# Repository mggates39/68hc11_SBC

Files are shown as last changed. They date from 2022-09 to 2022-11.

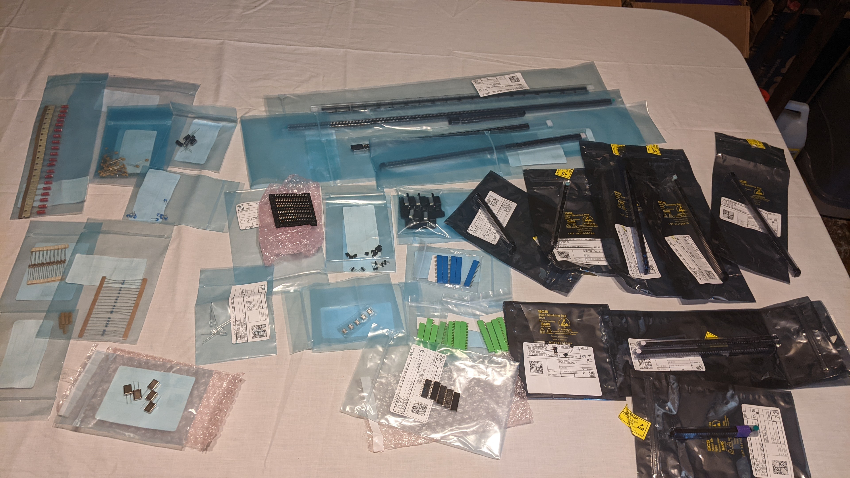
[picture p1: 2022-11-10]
BlogNotes/Digikey_Components/Components.jpg

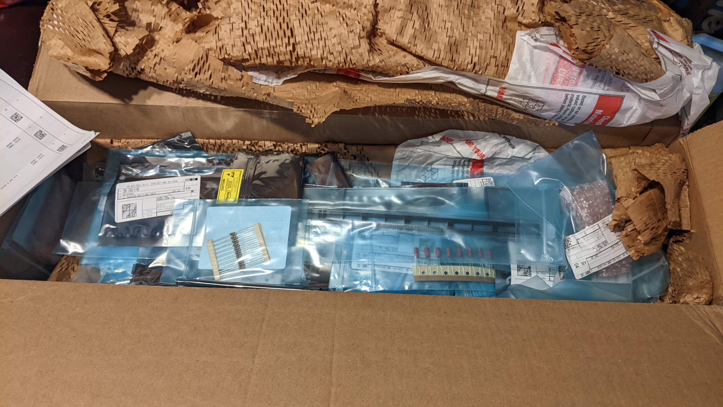
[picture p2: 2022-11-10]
BlogNotes/Digikey_Components/DigiKeyBox.jpg

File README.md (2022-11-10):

# 68hc11_SBC   [][License]
Building a Single Board Computer around the MC68HC11.  Specifically the XC68HC11A1FN - A38P8642.  It will include my first attempt with [KiCad](https://www.kicad.org/) designing a PCB

[][Manual]
[][Memory]

Software built with [TASM](https://www.ticalc.org/archives/files/fileinfo/250/25051.html)

Run in the [68HC11 Simulator](http://www.hc11.demon.nl/thrsim11/thrsim11.htm)

<!----------------------------------[ File links ]--------------------------------->

[License]: LICENSE
[Manual]: Documentation/Reference/68hc11%20Technical%20Manual.pdf
[Memory]: Documentation/Memory%20Map.md

<!----------------------------------[ Badges ]--------------------------------->

[Badge License]: https://img.shields.io/badge/License-GPL3-015d93.svg?style=for-the-badge&labelColor=blue

<!---------------------------------[ Buttons ]--------------------------------->

[Button Manual]: https://img.shields.io/badge/User_Manual-4285F4?style=for-the-badge&logoColor=white&logo=GitBook
[Button Memory]: https://img.shields.io/badge/Memory_Map-0F9D58?style=for-the-badge&logoColor=white&logo=Fitbit

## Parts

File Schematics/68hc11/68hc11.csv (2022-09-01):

Source: | /home/mggates/Dev/68hc11_SBC/Schematics/68hc11/68hc11.kicad_sch
Date: | Mon 29 Aug 2022 02:41:31 PM EDT
Tool: | Eeschema 6.0.2+dfsg-1
Generator: | /usr/share/kicad/plugins/bom_csv_grouped_by_value.py
Component Count: | 54
Individual Components:
Item | Qty | Reference(s) | Value | LibPart | Footprint | Datasheet
 |  | C1 | 100uF | Device:C_Polarized_US | Capacitor_THT:CP_Radial_D5.0mm_P2.00mm | ~
 |  | C2 | 0.1uF | Device:C_Polarized_US | Capacitor_THT:C_Disc_D3.0mm_W2.0mm_P2.50mm | ~
 |  | C3 | 0.1uF | Device:C_Polarized_US | Capacitor_THT:C_Disc_D3.0mm_W2.0mm_P2.50mm | ~
 |  | C4 | 0.1uF | Device:C_Polarized_US | Capacitor_THT:C_Disc_D3.0mm_W2.0mm_P2.50mm | ~
 |  | C5 | 0.1uF | Device:C_Polarized_US | Capacitor_THT:C_Disc_D3.0mm_W2.0mm_P2.50mm | ~
 |  | C6 | 0.1uF | Device:C_Polarized_US | Capacitor_THT:C_Disc_D3.0mm_W2.0mm_P2.50mm | ~
 |  | C7 | 0.1uF | Device:C_Polarized_US | Capacitor_THT:C_Disc_D3.0mm_W2.0mm_P2.50mm | ~
 |  | C8 | 0.1uF | Device:C_Polarized_US | Capacitor_THT:C_Disc_D3.0mm_W2.0mm_P2.50mm | ~
 |  | C9 | 0.1uF | Device:C_Polarized_US | Capacitor_THT:C_Disc_D3.0mm_W2.0mm_P2.50mm | ~
 |  | C10 | 0.1uF | Device:C_Polarized_US | Capacitor_THT:C_Disc_D3.0mm_W2.0mm_P2.50mm | ~
 |  | C11 | 22pF | Device:C | Capacitor_THT:C_Disc_D3.0mm_W1.6mm_P2.50mm | ~
 |  | C12 | 22pF | Device:C | Capacitor_THT:C_Disc_D3.0mm_W1.6mm_P2.50mm | ~
 |  | C13 | 10 uF | Device:C_Polarized_US | Capacitor_THT:CP_Radial_D5.0mm_P2.00mm | ~
 |  | C14 | 10 uF | Device:C_Polarized_US | Capacitor_THT:CP_Radial_D5.0mm_P2.00mm | ~
 |  | C15 | 10 uF | Device:C_Polarized_US | Capacitor_THT:CP_Radial_D5.0mm_P2.00mm | ~
 |  | C16 | 10 uF | Device:C_Polarized_US | Capacitor_THT:CP_Radial_D5.0mm_P2.00mm | ~
 |  | C17 | 0.1uF | Device:C_Polarized_US | Capacitor_THT:C_Disc_D3.0mm_W2.0mm_P2.50mm | ~
 |  | C18 | 0.1uF | Device:C_Polarized_US | Capacitor_THT:C_Disc_D3.0mm_W2.0mm_P2.50mm | ~
 |  | C19 | 0.1uF | Device:C_Polarized_US | Capacitor_THT:C_Disc_D3.0mm_W2.0mm_P2.50mm | ~
 |  | C20 | 0.1uF | Device:C_Polarized_US | Capacitor_THT:C_Disc_D3.0mm_W2.0mm_P2.50mm | ~
 |  | C21 | 0.1uF | Device:C_Polarized_US | Capacitor_THT:C_Disc_D3.0mm_W2.0mm_P2.50mm | ~
 |  | C22 | 0.1uF | Device:C_Polarized_US | Capacitor_THT:C_Disc_D3.0mm_W2.0mm_P2.50mm | ~
 |  | C23 | 0.1uF | Device:C_Polarized_US | Capacitor_THT:C_Disc_D3.0mm_W2.0mm_P2.50mm | ~
 |  | D1 | LED | Device:LED | LED_THT:LED_D5.0mm | ~
 |  | J1 | USB3076-30-A | Connector:USB_B_Micro | digikey-footprints:USB_Micro_B_Female_10118193-0001LF | ~
 |  | J2 | DB9_Female | Connector:DB9_Female_MountingHoles | Connector_Dsub:DSUB-9_Male_Horizontal_P2.77x2.84mm_EdgePinOffset4.94mm_Housed_MountingHolesOffset7.48mm | ~
 |  | J4 | Ports A and E | Connector:Conn_01x20_Female | Connector_PinSocket_2.54mm:PinSocket_1x20_P2.54mm_Vertical | ~
 |  | J5 | PIA 1 Ports A and B | Connector:Conn_01x20_Female | Connector_PinSocket_2.54mm:PinSocket_1x20_P2.54mm_Vertical | ~
 |  | J7 | Data Bus | Connector:Conn_01x10_Male | Connector_PinSocket_2.54mm:PinSocket_1x10_P2.54mm_Vertical | ~
 |  | J8 | PIA 2 Ports A and B | Connector:Conn_01x20_Female | Connector_PinSocket_2.54mm:PinSocket_1x20_P2.54mm_Vertical | ~
 |  | J11 | Address Bus | Connector:Conn_01x20_Female | Connector_PinSocket_2.54mm:PinSocket_1x20_P2.54mm_Vertical | ~
 |  | JP4 | BootSel | Jumper:Jumper_3_Bridged12 | Connector_PinHeader_2.54mm:PinHeader_1x03_P2.54mm_Vertical | ~
 |  | R1 | 330 | Device:R_US | Resistor_THT:R_Axial_DIN0204_L3.6mm_D1.6mm_P5.08mm_Horizontal | ~
 |  | R2 | 10M | Device:R_US | Resistor_THT:R_Axial_DIN0204_L3.6mm_D1.6mm_P5.08mm_Horizontal | ~
 |  | RN1 | 4.7 k | Device:R_Network07_US | Resistor_THT:R_Array_SIP8 | http://www.vishay.com/docs/31509/csc.pdf
 |  | SW1 | Reset | Switch:SW_Push | Button_Switch_THT:SW_PUSH_6mm | ~
 |  | U1 | MC68HC11A1CC-PLLC | MCU_NXP_HC11:MC68HC11A1CC-PLLC | Package_LCC:PLCC-52_THT-Socket
 |  | U2 | MC68B21 | Interface:MC68B21 | Package_DIP:DIP-40_W15.24mm | http://pdf.datasheetcatalog.com/datasheet/motorola/6821.pdf
 |  | U3 | 74HC373 | 74xx:74HC373 | Package_DIP:DIP-20_W7.62mm | https://www.ti.com/lit/ds/symlink/cd54hc373.pdf
 |  | U4 | 74HC245 | 74xx:74HC245 | Package_DIP:DIP-20_W7.62mm | http://www.ti.com/lit/gpn/sn74HC245
 |  | U5 | 74LS138 | 74xx:74LS138 | Package_DIP:DIP-16_W7.62mm | http://www.ti.com/lit/gpn/sn74LS138
 |  | U6 | 27C64 | Memory_EPROM:27C64 | Package_DIP:DIP-28_W15.24mm | http://ww1.microchip.com/downloads/en/DeviceDoc/11107M.pdf
 |  | U7 | 27C64 | Memory_EPROM:27C64 | Package_DIP:DIP-28_W15.24mm | http://ww1.microchip.com/downloads/en/DeviceDoc/11107M.pdf
 |  | U8 | HM62256BLP | Memory_RAM:HM62256BLP | Package_DIP:DIP-28_W15.24mm | https://web.mit.edu/6.115/www/document/62256.pdf
 |  | U9 | MAX232 | Interface_UART:MAX232 | Package_DIP:DIP-16_W7.62mm | http://www.ti.com/lit/ds/symlink/max232.pdf
 |  | U10 | MCP100-270D | Power_Supervisor:MCP100-270D | Package_TO_SOT_THT:TO-92 | http://ww1.microchip.com/downloads/en/DeviceDoc/11187f.pdf
 |  | U11 | 74LS138 | 74xx:74LS138 | Package_DIP:DIP-16_W7.62mm | http://www.ti.com/lit/gpn/sn74LS138
 |  | U12 | 74LS21 | 74xx:74LS21 | Package_DIP:DIP-14_W7.62mm | http://www.ti.com/lit/gpn/sn74LS21
 |  | U13 | 74LS32 | 74xx:74LS32 | Package_DIP:DIP-14_W7.62mm | http://www.ti.com/lit/gpn/sn74LS32
 |  | U14 | 74LS32 | 74xx:74LS32 | Package_DIP:DIP-14_W7.62mm | http://www.ti.com/lit/gpn/sn74LS32
 |  | U15 | 74LS04 | 74xx:74LS04 | Package_DIP:DIP-14_W7.62mm | http://www.ti.com/lit/gpn/sn74LS04
 |  | U16 | 27C64 | Memory_EPROM:27C64 | Package_DIP:DIP-28_W15.24mm | http://ww1.microchip.com/downloads/en/DeviceDoc/11107M.pdf
 |  | U17 | MC68B21 | Interface:MC68B21 | Package_DIP:DIP-40_W15.24mm | http://pdf.datasheetcatalog.com/datasheet/motorola/6821.pdf
 |  | Y1 | 8.0 MHz | Device:Crystal | Crystal:Crystal_HC49-4H_Vertical | ~
Collated Components:
Item | Qty | Reference(s) | Value | LibPart | Footprint | Datasheet
1 | 1 | C1 | 100uF | Device:C_Polarized_US | Capacitor_THT:CP_Radial_D5.0mm_P2.00mm | ~
2 | 16 | C2, C3, C4, C5, C6, C7, C8, C9, C10, C17, C18, C19, C20, C21, C22, C23 | 0.1uF | Device:C_Polarized_US | Capacitor_THT:C_Disc_D3.0mm_W2.0mm_P2.50mm | ~
3 | 2 | C11, C12 | 22pF | Device:C | Capacitor_THT:C_Disc_D3.0mm_W1.6mm_P2.50mm | ~
4 | 4 | C13, C14, C15, C16 | 10 uF | Device:C_Polarized_US | Capacitor_THT:CP_Radial_D5.0mm_P2.00mm | ~
5 | 1 | D1 | LED | Device:LED | LED_THT:LED_D5.0mm | ~
6 | 1 | J1 | USB3076-30-A | Connector:USB_B_Micro | digikey-footprints:USB_Micro_B_Female_10118193-0001LF | ~
7 | 1 | J2 | DB9_Female | Connector:DB9_Female_MountingHoles | Connector_Dsub:DSUB-9_Male_Horizontal_P2.77x2.84mm_EdgePinOffset4.94mm_Housed_MountingHolesOffset7.48mm | ~
8 | 1 | J4 | Ports A and E | Connector:Conn_01x20_Female | Connector_PinSocket_2.54mm:PinSocket_1x20_P2.54mm_Vertical | ~
9 | 1 | J5 | PIA 1 Ports A and B | Connector:Conn_01x20_Female | Connector_PinSocket_2.54mm:PinSocket_1x20_P2.54mm_Vertical | ~
10 | 1 | J7 | Data Bus | Connector:Conn_01x10_Male | Connector_PinSocket_2.54mm:PinSocket_1x10_P2.54mm_Vertical | ~
11 | 1 | J8 | PIA 2 Ports A and B | Connector:Conn_01x20_Female | Connector_PinSocket_2.54mm:PinSocket_1x20_P2.54mm_Vertical | ~
12 | 1 | J11 | Address Bus | Connector:Conn_01x20_Female | Connector_PinSocket_2.54mm:PinSocket_1x20_P2.54mm_Vertical | ~
13 | 1 | JP4 | BootSel | Jumper:Jumper_3_Bridged12 | Connector_PinHeader_2.54mm:PinHeader_1x03_P2.54mm_Vertical | ~
14 | 1 | R1 | 330 | Device:R_US | Resistor_THT:R_Axial_DIN0204_L3.6mm_D1.6mm_P5.08mm_Horizontal | ~
15 | 1 | R2 | 10M | Device:R_US | Resistor_THT:R_Axial_DIN0204_L3.6mm_D1.6mm_P5.08mm_Horizontal | ~
16 | 1 | RN1 | 4.7 k | Device:R_Network07_US | Resistor_THT:R_Array_SIP8 | http://www.vishay.com/docs/31509/csc.pdf
17 | 1 | SW1 | Reset | Switch:SW_Push | Button_Switch_THT:SW_PUSH_6mm | ~
18 | 1 | U1 | MC68HC11A1CC-PLLC | MCU_NXP_HC11:MC68HC11A1CC-PLLC | Package_LCC:PLCC-52_THT-Socket
19 | 2 | U2, U17 | MC68B21 | Interface:MC68B21 | Package_DIP:DIP-40_W15.24mm | http://pdf.datasheetcatalog.com/datasheet/motorola/6821.pdf
20 | 1 | U3 | 74HC373 | 74xx:74HC373 | Package_DIP:DIP-20_W7.62mm | https://www.ti.com/lit/ds/symlink/cd54hc373.pdf
21 | 1 | U4 | 74HC245 | 74xx:74HC245 | Package_DIP:DIP-20_W7.62mm | http://www.ti.com/lit/gpn/sn74HC245
22 | 2 | U5, U11 | 74LS138 | 74xx:74LS138 | Package_DIP:DIP-16_W7.62mm | http://www.ti.com/lit/gpn/sn74LS138
23 | 3 | U6, U7, U16 | 27C64 | Memory_EPROM:27C64 | Package_DIP:DIP-28_W15.24mm | http://ww1.microchip.com/downloads/en/DeviceDoc/11107M.pdf
24 | 1 | U8 | HM62256BLP | Memory_RAM:HM62256BLP | Package_DIP:DIP-28_W15.24mm | https://web.mit.edu/6.115/www/document/62256.pdf
25 | 1 | U9 | MAX232 | Interface_UART:MAX232 | Package_DIP:DIP-16_W7.62mm | http://www.ti.com/lit/ds/symlink/max232.pdf
26 | 1 | U10 | MCP100-270D | Power_Supervisor:MCP100-270D | Package_TO_SOT_THT:TO-92 | http://ww1.microchip.com/downloads/en/DeviceDoc/11187f.pdf
27 | 1 | U12 | 74LS21 | 74xx:74LS21 | Package_DIP:DIP-14_W7.62mm | http://www.ti.com/lit/gpn/sn74LS21
28 | 2 | U13, U14 | 74LS32 | 74xx:74LS32 | Package_DIP:DIP-14_W7.62mm | http://www.ti.com/lit/gpn/sn74LS32
29 | 1 | U15 | 74LS04 | 74xx:74LS04 | Package_DIP:DIP-14_W7.62mm | http://www.ti.com/lit/gpn/sn74LS04
30 | 1 | Y1 | 8.0 MHz | Device:Crystal | Crystal:Crystal_HC49-4H_Vertical | ~

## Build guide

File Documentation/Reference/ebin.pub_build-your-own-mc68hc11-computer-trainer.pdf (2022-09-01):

Copyright © 1999 by Geoffrey C. Yerem, First Printing

# Build Your Own MC68HC11 Computer Trainer

Geoffrey C. Yerem
Department of Electrical Engineering University of Tennessee, Knoxville

### 1 Introduction

The electronic computer has been called the most complex machine built by man, and anyone fascinated by technology recognizes the computer as the ultimate machine. Infinitely configurable through programming, the computer is a machine that is malleable as clay is to a skilled sculptor. If you love computers, you probably want to become a skilled computer sculptor. Becoming a skilled programmer provides half of the skills you need. Completing your skills means understanding computer hardware, at the heart of which is the microprocessor. If learning about computer hardware is your goal, then read on. This paper is going to show you how to build your own practical, working computer from scratch.

This document will show you how to build your own computer trainer based on the Motorola MC68HC11 microprocessor. The design used here is similar to many of the commercially available MC68HC11 single board computers, particularly the Motorola M68HC11 Evaluation Board (EVB). You will learn a great deal by building this project and, in the end, you will have a working EVB of your very own that you can program and customize.

This document contains six sections:

Section 1 - Introduction
Section 2 - The Structure of a Small Computer System Section 3 - Building the Computer
Section 4 - Testing the Computer
Section 5 - Using the Computer
Section 6 - Conclusion

The instructions in the rest of this document assume that you have had little or no exposure to microprocessor electronics. You should, though, have some computer programming experience, particularly with assembly language. Also, you should have some experience with digital electronics as well as some experience with basic electronic assembly. Barring no problems, you can construct this project in about one full week. Good luck, you are on your way to building your first, but probably not your last, computer.

2 Yerem: Build Your Own MC68HC11 Computer Trainer

### 2 The Structure of a Small Computer System

| The purpose of a computer is to act out a series of directions given by a person, ultimately performing some physical action. This goal starts with numbers. Numbers, as it turns out, can represent any type of information. Since computers manipulate numbers, computers also manipulate representations of information. The form of numbers that electronic computers use are groups of binary digits or bits. Bits are simply numerical digits which only have two states, 0 and 1. This is just like a digit in our decimal system which has ten states, 0 through 9, one state for each finger on our two hands. So you might say that by using the binary system, a computer probably has only one finger on each of its hands! A consequence of bits having fewer states than decimal digits is that you need more binary digits to represent the same number in the decimal system. Nonetheless, both number systems can each represent every possible number. Ultimately, electronic computers use binary digits because by only having two states it has a minimal chance of confusing one state with the other and that provides a maximum level of reliability.
| A computer uses its electronic versions of numbers to perform its purpose; acting out a series of directions given by a person. Since numbers can represent anything, we can use numbers to represent the instructions that we want the computer to follow as well as raw information and even some physical actions like turning on an indicator light, sending messages to a teletype or making a sound.
| The microprocessor chip contains all of the electronics needed to perform a majority if not all of the actions of a computer system. Usually though, a certain amount of the resources of a computer are too expensive or impractical to squeeze onto one integrated circuit chip. The most notable of these resources is memory. Memory is the single most expensive element of a computer system. Memory gives the computer a place to store numbers. The more memory a computer has, the more numbers it can store. Computer memory typically stores raw data and programs.
| If a microprocessor is going to work with external memory it needs external signals to control the memory. These signals can be broken into three parts: an address bus, a data bus and a control bus.
| The address bus is a series of digital signal lines which can send out a binary number which in turn represents a single location in the computer’s memory space. Since the address bus can only represent a finite amount of unique numbers, there can only be a finite number of memory locations in a computer system.
| Once you have a place to store numbers, you need a way access them. That’s where the data bus comes in. Just like the address bus, the data bus is a series of digital signal lines which can send and receive numbers. In this case, the numbers represents raw data, physical actions or a program.
| Finally, the control bus uses its digital signals to keep the address and data busses of the microprocessor synchronized with the external components.

### 2.1 The Design

The computer we are about to build will have the Motorola MC68HC11 microprocessor at its core. Motorola designed the MC68HC11 so that it requires a minimum of support circuitry in order to build a working design with it. This will suit our purposes nicely since it will allow us to learn how to build a computer without sinking in excessive complexity.

XTAL | EXTAL
30 | 29

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
*IRQ
*XIRQ

25
24

*RESET

28

27

26
E

40

41

39

MODB(Vstby)

MODA(*LIR)

(U1)
MC68HC11A1P

AS

R/*W

PE0/AN0

PE1/AN1

PE2/AN2

PE3/AN3

PD0/RxD

PD1/TxD

PD2/MISO

PD3/MOSI

PD4/SCK

PD5/*SS

PA0/IC3

PA1/IC2

PA2/IC1

PA3/OC5/OC1

PA4/OC4/OC1

PA5/OC3/OC1

PA6/OC2/OC1

PA7/PAI/OC1

The MC68HC11 has many useful circuits already built into it. For example, it has built-in digital I/O ports, a sophisticated timing system, an asynchronous serial port for RS-232 communications, a synchronous serial port, an analog-to-digital converter and a built-in crystal oscillator circuit. It also has built-in memory such as 256 bytes of Random Access Read/Write Memory (RAM), 512 bytes of Electrically Erasable Programmable Read Only Memory (EEPROM) and in some versions, 8 kB of Read Only Memory (ROM). Having all these resources on one chip allows the MC68HC11 to be used as a single-chip microcontroller requiring no extra support chips. For this project though, we will treat the MC68HC11 as a conventional microprocessor by adding various external resources to it.

Following is a block-by-block description of the computer’s design using sections taken from the main schematic diagram. The complete schematic diagram can be found in Appendix 3.

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
38 AD7 | 19 | 1

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
74HC245
(U4)

(U3)
74HC373

Address Bus (A0:A15)

AS

R/*W

*PIA2

R/*W

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
8 | 9

7

*BOOT
*SPARE

*RDIO

PAL16L8-12

12

I
I
I
I
I
I

*WRIO

*PIA1
*EXTRA
*RAM

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
(U5)

### 1. This is the address/data demultiplexer

circuit. It separates the one address/data bus into distinct address and data busses. Multiplexing the address and data bus saves 8 pins which can be dedicated to other resources at the expense of requiring an external demultiplexing circuit.

### 2. This is the Chip Select PAL. Its job is to

decode the address space and select the appropriate memory chip. Its inputs are the address lines as well as the E and R/*W lines. Its outputs are the various chip select signals.

25
24

Vcc

MODB(Vstby)

MODA(*LIR)

(RP1)
4.7 kΩ
(U1)
MC68HC11

J4

Vcc

PE0

### 3. These are the mode pins. These two pins

allow you to configure the MC68HC11 to run in one of four modes. Pulling both pins high, as in this case, puts the microprocessor in Expanded Mode.

### 4. This is the “J4” jumper. The BUFFALO

monitor program uses this jumper to determine whether or not to jump to the internal EEPROM or run the BUFFALO monitor at startup.

XTAL | EXTAL
30 | 29
(R2) 10 MΩ

(Y1) 8.0 MHz

(C11)
22 pF

(C12)
22 pF

LVI

2

3

1

RESET

Vcc

Vcc

(U10)
MN13811-Q

(RP1)
4.7 kΩ

### 5. This is the oscillator circuit. It provides

the “heartbeat” for the microprocessor. The oscillator generates an 8 MHz square wave which is divided internally by a factor of four to supply a 2 MHz clock pulse to the microprocessor.

### 6. This is the reset circuit. Pressing the Reset

button will cause the computer to stop what it is doing and start from scratch. The LVI (Low Voltage Interrupt) chip can also assert the Reset line if the power supply voltage drops below 4 V. This prevents the microprocessor from running before the power reaches a meaningful level.

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
Vpp 27
*PGM

Vcc

(U6)
27C64-250
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
2 A12 A11 A10 A9 A8 A7 A6 A5 A4 A3 A2 A1 A0

I/O7
I/O6
I/O5
I/O4
I/O3
I/O2
I/O1
I/O0

22
*OE
*CE

R/*W

A13

A14 1 A14
26 A13

20

27

(U8)
HM62256-LP15

Data Bus (D0:D7)

Address Bus (A0:A15)

### 7. This is one of the two EPROMs (Erasable

Programmable Read Only Memory). The computer uses this memory chip to store programs and data semi-permanently. In other words, the information stored here can only be erased by shining an ultraviolet light into the glass window on the chip.

### 8. This is the RAM (Random Access

Memory) chip. While the MC68HC11 has 256 bytes of RAM internally, this usually is not enough for software development. The HM62256 provides the computer with an additional 32 kB of R/W memory.

Notice that the EPROM and the RAM chip have similar pin outs. This is due to the JEDEC standard which specifies the pin outs of byte-wide (8-bit) memory devices. The JEDEC standard allows memory of different sizes and from different manufacturers to be used in the same sockets, with little or no modifications.

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
V+ | V- C2+ C2-

(U9)
MAX232CPE | 1
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
(C14)
10µF

(C13)
10µF

(C15)
10µF

(C16)
10µF

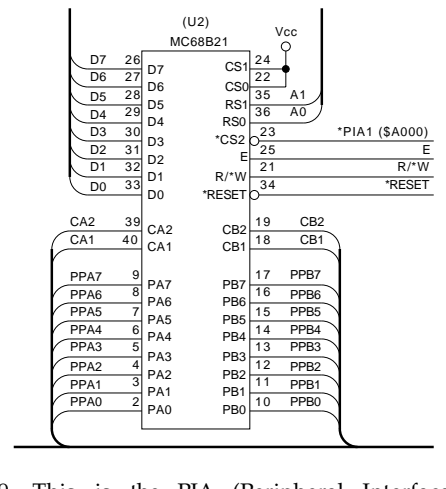
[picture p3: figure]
E R/*W *RESET; Vcc; PPA7 PPA6 PPA5 PPA4 PPA3 PPA2 PPA1 PPA0; PPB0; PPB1; PPB2; PPB3; PPB4; PPB5; PPB6; PPB7; *PIA1 ($A000)

### 9. This is the PIA (Peripheral Interface

Adapter) chip. Since we are using the MC68HC11 in expanded mode, I/O ports B and C are unavailable for our use. The MC6821 will give us two bi-directional 8-bit I/O ports to work with.

### 10. This is the RS-232 circuit. The MAX232

provides the interface between the serial port on the MC68HC11 and the DB-9 connector. This buffer chip is required because RS-232 requires relatively high voltages (about ±12 V). Additionally, the MAX232 has a charge pump circuit which uses four capacitors to generate ±10 VDC from the 5V supply. This way the whole computer can run from a single 5V supply.

Additionally, the computer requires a +5 VDC @ 0.3 A power supply. For this project, you can either purchase one or build a simple one from scratch.

Keep in mind that this design isn’t inscribed in stone. Feel free to modify the computer in any way you see fit. You can learn a great deal by customizing the computer.

### 3 Building the Computer

Before you start ordering the parts and constructing the computer, skim through this whole document to get an idea of what to expect. While this document is presented in chronological order, you can avoid many pitfalls as you’re building the computer if you know where you’re heading.

To build this computer you will need some common pieces of electronic tools and test equipment. The major tools you will need access to are an EPROM programmer and a 15 W soldering iron with a small tip. The test equipment you will need are a +5 VDC power supply, a voltmeter, a personal computer with an RS-232 serial port, a terminal emulation program and possibly an oscilloscope. Additionally, it would help to have access to the World Wide Web.

The following timeline depicts a minimum-time schedule required to complete this project. If all goes well, you can probably finish this project in a week or two. Keep in mind though that this estimate does not include the time required to overcome learning how to build a computer or the time required to debug the computer which can be two large variables in this schedule. Of course, overcoming these obstacles embodies the whole purpose of this project.

Monday | Order Parts.
| Download Software.
Order Data Sheets.
Tuesday | Buy parts from Radio Shack.
Wednesday | Receive Mail Order Parts.
Thursday | Program PAL and EPROM. Lay out the board.
Friday | Wire the computer.
Saturday | Wire the computer.
Sunday | Test the computer.

### 3.1 Ordering the Parts

Mail-order is the best way to obtain electronic parts. While it’s tempting to run down to the local electronics store and buy the parts off the shelf, you will usually have trouble getting exactly what you need and wind up paying a lot extra. With mail-order, you can almost always get exactly what you want at a good price. All you need is a credit card and a telephone. Begin signing up on the mailing lists of mail-order houses which sell electronic parts. This is easy to do since every major mail-order house has a toll-free number as well as a World Wide Web (WWW) site.

There are three parts listings given for this project, one for each parts supplier. Generally, the fewer orders you make, the less overall shipping charges you have to pay. It turns out that JDR Microdevices, Digi-Key and Radio Shack have all of the parts that we’ll need. JDR Microdevices and Digi-Key are mail-order houses, while Radio Shack is usually just a car ride away.

Keep in mind that the parts list, and the whole design for that matter, isn’t etched in stone. If you find a better supplier, come up with better parts, or just want to save money, many of these parts can be substituted or even left out entirely. Look over the part list carefully and check the items with the mail-order catalogs. Try to understand what you’re buying.

If you find that a particular part isn’t in stock, it would be best to substitute the part for another or order it somewhere else, as opposed to backordering the part. Backorders can mean waiting weeks or possibly not getting the part a t all, not to mention extra shipping charges. Be sure to keep the mail-order catalog handy when you place your order in case you need to make a quick substitution. Backorders shouldn’t be a problem for this project since most of the parts are pretty commonplace.

If you choose, you can order all of the mail-order parts over the Internet. Simply go to the respective WWW site and follow the ordering procedure. One advantage to ordering parts over the Internet is that you can instantaneously check the stock for each item as you go along. Also, you won’t feel rushed in case you need to change your mind while ordering.

If you place your order early in the day, the parts suppliers will usually ship the order the same day. As a result, the shipping method you choose will determine the amount of time it will take to get the parts. Second-day air-mail is usually a good buy. With second-day air-mail, the parts will arrive within two business days of when they are shipped.

The prices and part numbers which are listed below reflect what was available at the time of printing. As time progresses, the prices, availability and part numbers will change. If you can't find a part in the recent catalogs, find substitutes using the master parts list in Appendix 1.

The parts marked (*) are ones you might already have in your parts box. I f you don't have them, go ahead and order them since you're getting a pretty good deal from the mail-order houses. The parts marked (†) are optional and can be substituted for something less exotic.

Digi-Key, 1-800-344-4539 (http://www.digikey.com)
# | Part No. | | Part Description | Unit Price | Total Price

1 1 1 1 1 1 1 1 | AE1020-ND ED1609-ND ED4648-ND MN13811-Q-ND EG1403-ND 923252-ND 923292-ND L20165-ND | * * * † † * | Male-Female DB-9 Cable (2m) 2 Position Terminal Block 48-Pin DIP WW Socket 3-Level 3.8V O.D. Low Voltage Detector SPST Momentary Square Yellow Pushbutton 6.5" Solderless Breadboard w/Power Busses 54 Point Terminal Strip with Solder Tails PC Board Mount Green LED With Holder | 5.35 0.37 5.49 0.85 0.98 19.25 9.65 0.67 | 5.35 0.37 5.49 0.85 0.98 19.25 9.65 0.67
| | | Sub Total | | $42.61

JDR Microdevices, 1-800-538-5000 (http://www.jdr.com)
# | Part No. | | Part Description | Unit

| | | | Price | Total
| | | | | Price
| | | Integrated Circuits
1 | 74HC245 | | Octal Tri-State Transceiver | 0.39 | 0.39
1 | 74HC373 | | Octal Tri-State D Type Latch | 0.45 | 0.45
1 | MAX232CPE | | +5V Powered Dual RS-232 Trans./Rcvr. | 1.39 | 1.39
1 | 68HC11A1P | | 8-bit HCMOS MCU | 11.99 | 11.99
1 | 68B21 | 2 | PIA 2 MHz | 2.89 | 2.89
2 | 27C64A-200 | | 8kx8 250ns EPROM | 2.89 | 5.78
1 | HM62256LP-10 | | 32kx8 100ns Static RAM | 1.99 | 1.99
1 | 16L8B | | PAL 16L8B 15ns | 1.49 | 1.49
| | | Discrete Components
1 | 8.0MHZ | | 8.0 MHz Crystal | 1.39 | 1.39
1 | RPS7-4.7K | † | 4.7 kΩ SIP 7 Resistor Network | 0.19 | 0.19
10 | R10.0M | * | 10 MΩ 1/4 W Resistor | 0.05 | 0.50
10 | R330 | * | 330 Ω 1/4 W Resistor | 0.05 | 0.50
1 | 100R16 | * | 100 µF 16V Radial Electrolytic Capacitor | 0.14 | 0.14
4 | 10R63 | * | 10 µF 63V Radial Electrolytic Capacitor | 0.10 | 0.40
2 | 22PF | * | 22 pF Ceramic Capacitor | 0.05 | 0.10
9 | T.1-35 | * | 0.1 µF Tantalum Capacitor | 0.15 | 1.35
| | | Connectors
1 | DB09SRS | | Right Angle PC Mount Female DB-9 Connector | 0.59 | 0.59
| | | IC Sockets
1 | 16 PIN WW | | 16-Pin DIP WW Socket 3-Level | 0.79 | 0.79
3 | 20 PIN WW | | 20-Pin DIP WW Socket 3-Level | 1.09 | 3.27
3 | 28 PIN WW | | 28-Pin DIP WW Socket 3-Level | 1.49 | 4.47
1 | 40 PIN WW | | 40-Pin DIP WW Socket 3-Level | 1.69 | 1.69
| | | Headers
10 | JUMPER-KT-10 | † | Shorting Jumper Block | 0.99 | 0.99
1 | HDR-40R | † | 1x40 Snappable Header with Right Angle Pins | 0.89 | 0.89
| | | Sub Total | | $43.63

Radio Shack (http://www.radioshack.com)
# | Part No. | | Part Description | Unit Price | Total Price

1 1 1 | 278-503 276-1396 276-1570 | * | 50' 30-Gauge Blue Wrapping Wire 6"x8” IC-Spacing Perfboard Wire-Wrapping Tool | 2.79 3.49 7.49 | 2.79 3.49 7.49
| | | Sub Total | | $13.77

### 3.2 Downloading the Software

While you are waiting for the parts to arrive, you can download the software required for the computer from the Internet. Motorola has an FTP site which has lots of free software that can be used for developing computers based on Motorola microprocessors. For this project, the one important piece of software required is the BUFFALO monitor program. BUFFALO is a stand alone program written for operating a simple MC68HC11 computer through a dumb terminal. We will put the BUFFALO program in an 8 kB boot EPROM so that the computer will be ready for work at power up.

Additionally, there are two other pieces of software that would be useful for this project. The AS11 program is a freeware cross-assembler provided by Motorola. It’s invaluable for writing software for the MC68HC11. Also, the FTP site has a copy of BASIC11, a stand alone BASIC interpreter for the MC68HC11. The interpreter is fairly complete and fits inside of an 8 kB ROM.

The Motorola FTP site is located at:
http://www.mot.com/pub/SPS/MCU/

Alternatively, the University of Alberta Motorola Archive is a mirror site: ftp://nyquist.ee.ualberta.ca/pub/motorola/

Download the BUFFALO Monitor - You only need the “.s19” file, but if you want an up-to-date source listing for BUFFALO, then download the “.zip” file.

Path | Size | Date | Comments
/mon/buf34.s19 (http://www.mot.com/pub/SPS/MCU/mon/buf34.s19) | 19182 | 03/30/1994 | BUFFALO 3.4 monitor for the
HC11.
/mon/buf34.zip (http://www.mot.com/pub/SPS/MCU/mon/buf34.zip) | 116221 | 03/02/1995 BUFFALO 3.4 monitor for the
HC11 with source code.

Download a cross-assembler - AS11 is a freeware cross-assembler for the MC68HC11. It has been ported to many platforms since Motorola has distributed the C source code for the assembler.

Path | Size | Date | Comments
/ibm/as11.exe (http://www.mot.com/pub/SPS/MCU/ibm/as11.exe) | 18870 | 03/30/1994 | Cross | assembler | for | the
MC68HC11.
/ibm/as11new.exe (http://www.mot.com/pub/SPS/MCU/ibm/as11new.exe) | 19584 | 03/30/1994 | Improved version of as11.
/mac/XASMHC11.MAC (http://www.mot.com/pub/SPS/MCU/mac/XASMHC11.MAC) | 49024 | 03/30/1994 | This is as11 ported to the
Macintosh by Georgia Tech. Use MacBinary to download
this application.

While you’re downloading software you might want to get a copy of PALASM. PALASM is a freeware program from American Micro Devices (AMD) which you can use to compile the program for the Chip Select PAL.

The AMD WWW site is located at: http://www.vantis.com/software/software.html (http://www.vantis.com/software/software2.html)

Download PALASM - When you reach the web site, follow the registration procedure for downloading PALASM.

### 3.3 Ordering the Data Sheets

Component manufacturers publish data books and data sheets for all of their components. Usually the literature and the phone call are free. Additionally, most major manufacturers have World Wide Web sites which have the literature in electronic form.

For this project, it would be a good idea to get the data sheets for some of the components. Particularly, the data sheets for the MC68HC11 and the MC6821 are indispensable.

You have two options for ordering the literature. You can either call up Motorola literature group or you can access their WWW site. I would recommend using the WWW site since it is as simple as filling out a form. If you choose to go to Motorola’s web site, be sure to browse around to see the other services they provide.

Here is the phone number for the Motorola Literature Distribution: 1-800-441-2447

While here is their WWW address: http://mot2.mot-sps.com/home/lit_ord.html

Here are the part numbers for the data books to order:

MC68HC11A8/D | MC68HC11A8 Technical Data Book
MC6821/D | MC6821 Peripheral Interface Adapter Data Sheet
M68HC11EVB/D1 M68HC11EVB Evaluation Board User's Manual

### 3.4 Construction

Now that the parts have arrived, it is time to assemble your computer. We will start by programming the boot EPROM and the chip select PAL. Following will be a tutorial on wire-wrapping. Finally, we will lay out the components on the board and do the actual wiring.

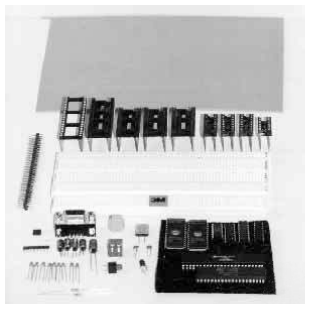
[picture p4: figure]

### 3.4.1 Programming the EPROMs

The boot ROM will give our computer a program to run every time the computer is powered up. This is possible since the boot ROM provides non-volatile storage (it doesn’t lose its memory when the power is turned off).

This step will require the use of an EPROM programmer. This might be troublesome if you don’t have access to one. Since an EPROM programmer can be an expensive item, you might want to get help from someone who owns one. The Electrical Engineering department at your local university would have one as well as your local electronics trade school. It is also possible that your local electronics repair shop would have one that you can use. If these options aren’t available to you or if you think you will be building more computers in the future, you might want to invest in your own personal EPROM programmer. Most electronics supply stores carry them. For this project, be sure that the programmer you use is able to program both EPROMs and PALs.

You can erase an EPROM by using an EPROM eraser which contains an ultraviolet lamp. The ultraviolet light is shined through the window on the chip. Never look directly at an ultraviolet lamp as it can cause serious eye damage.

Programming the Buffalo EPROM

### 1. Load the “buf34.s19” file into the EPROM programmer. You might

have to tell it that the file is in Motorola Hex format. Specify a base address of $E000.

2. Program and verify the BUFFALO EPROM.

Programming the Test EPROM
1. Store the test program in Listing 1 into a text file.

Listing 1: The test program listing.

**** test.as ****
RegBase equ $1000
PORTA | equ $00
TCTL1 | equ $20
TFLG2 | equ $25
PACTL | equ $26
PIA_PRA equ $A000
PIA_CRA equ $A001
PIA_PRB equ $A002
PIA_CRB equ $A003
| org | $E000
start | ldx | #RegBase
| clr | PIA_CRA | Initialize PIA.
| clr | PIA_CRB
| ldaa | #$FF
| staa | PIA_PRA
| staa | PIA_PRB
| ldaa | #$04
| staa | PIA_CRA
| staa | PIA_CRB
| ldaa | #$80
| staa | PACTL,x
| clr | TCTL1,x
| ldab | #$38 | Initialize test pattern.
| clc
delay | ldy | #7 | Wait 0.23 seconds by counting seven timer overflows.
loop | brclr TFLG2,x $80 loop Wait for timer overflow.
| ldaa | #$80
| staa | TFLG2,x | Clear timer overflow flag.
| dey
| bne | loop
| rolb | | Rotate test pattern.
| stab | PORTA,x | Write test pattern.
| stab | PIA_PRA
| stab | PIA_PRB
| bra | delay
| org | $FFFE
| fdb | start
2. Assemble the program using the AS11 assembler.

### 3. Load the resulting .s19 file into the EPROM programmer as before

specifying a base address of $E000.

4. Program and verify the test EPROM.

### 3.4.2 Programming the Chip Select PAL

The Chip Select PAL (Programmable Array Logic) chip is used to perform the logic which “glues” the computer together. By using a PAL, we reduce the number of components by eliminating many discrete logic gates. The PAL can provide much more complex designs than normally would be attempted with discrete logic. Also, if the logic needs to change, a new chip can be programmed replacing the old design.

Since all of the memory and I/O chips share the same data and address busses, they need a way to know when they are being addressed. The PAL will do this job by decoding the current value on the address bus and selecting the appropriate chip. Additionally, the PAL gates the RAM and ROM chip select signals with the E clock signal since the data bus isn’t ready until E is high. Also, the ROM chip selects are gated with the R/*W line so that the ROM is only selected during a read cycle.

Programming the PAL

### 1. Using a text editor, type in the program shown in Listing 2 and save i t

in a text file.

Listing 2: The program listing for the Chip Select PAL.

;---------------------------------- Declaration Segment ------------TITLE EVB Address Decoder
PATTERN
REVISION
AUTHOR G. Yerem
COMPANY UTK
DATE 06/19/97
CHIP _CSPAL PAL16L8

;---------------------------------- PIN Declarations ---------------
PIN 1 | A15 | COMBINATORIAL ; INPUT
PIN 2 | A14 | COMBINATORIAL ; INPUT
PIN 3 | A13 | COMBINATORIAL ; INPUT
PIN 4 | A12 | COMBINATORIAL ; INPUT
PIN 5 | A11 | COMBINATORIAL ; INPUT
PIN 6 | A10 | COMBINATORIAL ; INPUT
PIN 7 | RW_EN | COMBINATORIAL ; INPUT
PIN 8 | IO_EN | COMBINATORIAL ; INPUT
PIN 9 | RW | COMBINATORIAL ; INPUT
PIN 10 | GND | ; GND
PIN 11 | E | COMBINATORIAL ; INPUT
PIN 12 | /RAM_SEL | COMBINATORIAL ; OUTPUT
PIN 13 | /EXTRA_SEL | COMBINATORIAL ; OUTPUT
PIN 14 | /PIA1_SEL | COMBINATORIAL ; OUTPUT
PIN 15 | /PIA2_SEL | COMBINATORIAL ; OUTPUT
PIN 16 | /RDIO_SEL | COMBINATORIAL ; OUTPUT
PIN 17 | /WRIO_SEL | COMBINATORIAL ; OUTPUT
PIN 18 | /SPARE_SEL | COMBINATORIAL ; OUTPUT
PIN 19 | /BOOT_SEL | COMBINATORIAL ; OUTPUT
PIN 20 | VCC | ; VCC

;----- Boolean Equation Segment. ----
EQUATIONS
RAM_SEL | = (/A15)*E | ; $0000 - $7FFF
EXTRA_SEL = ( A15*/A14*/A13)*E*RW | ; $8000 - $9FFF
PIA1_SEL = ( A15*/A14* A13*/A12*/A11*/A10) | ; $A000 - $A3FF
PIA2_SEL = ( A15*/A14* A13*/A12*/A11* A10) | ; $A400 - $A7FF
RDIO_SEL = ( A15*/A14* A13*/A12* A11*/A10 + IO_EN)*(E* RW + RW_EN) ; $A800 - $ABFF WRIO_SEL = ( A15*/A14* A13*/A12* A11* A10 + IO_EN)*(E*/RW + RW_EN) ; $AC00 - $AFFF
SPARE_SEL = ( A15* A14*/A13)*E*RW | ; $C000 - $DFFF
BOOT_SEL = ( A15* A14* A13)*E*RW | ; $E000 - $FFFF

### 2. Using PALASM or a similar program, compile the PAL program to

generate a JEDEC file. (PALASM is a freeware program from AMD which runs under DOS.)

3. Using an EPROM programmer, program the PAL using the JEDEC file.

You can test your PAL by placing it in a solderless breadboard and examining the outputs for different input combinations.

### 3.4.3 Board Layout

The next step is to lay out the components on the board.

First place the sockets and discrete components on the perfboard. The scale drawing in Appendix 2 offers a suggested layout. Keep in mind that the DIP wire-wrap sockets have an indentation which marks pin 1 of the chip. The indentation on the socket corresponds to the indentation on the chip itself.

Next label the underside of the board. This will prevent errors when you are wiring the board. It can be very frustrating to finish wiring a project, only to find out that you’ve wired the chips backwards. White adhesive correction tape, which can be found at office supply stores, works good for this purpose. Also, you can buy preprinted labels for wire-wrapping if you don’t want to make the labels yourself. For this project, Appendix 4 has some pre-printed labels that you can cut out and glue to the board.

Now remove the discrete components and carefully turn the board over. Cut out the labels in Appendix 4 and glue them underneath the appropriate sockets. A knife and tweezers are helpful for placing the labels. Also, double check to make sure you have the orientations correct.

### 3.4.4 How to Wire Wrap

Wire wrapping involves spinning 30-gauge wire onto special sockets with rectangular posts in order to make point-to-point electrical connections. Does that sound simple? Well, actually it is. Wire wrap connections are very reliable and well suited for digital signals.

Some tools you might find useful for wire-wrapping are: tweezers, a wire-wrapping tool, an X-Acto knife, diagonal cutters, needle nose pliers, and a wrapping wire dispenser.

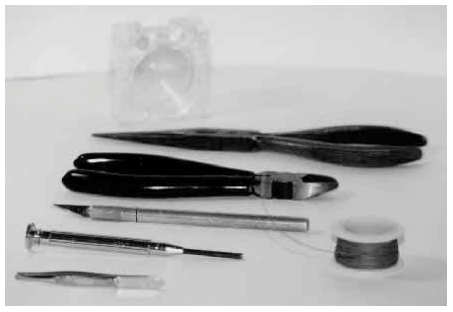
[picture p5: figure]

Here is a close-up picture of the wire-wrapping tool that Radio Shack sells. It’s a manual tool which is very reliable. Also, hidden in the handle you will find a handy wire stripper.

If you shop around you will find that there are many varieties of wire-wrapping tools available. Some tools will dispense, strip and cut the wire automatically for you and some are also motorized to spin the wire for you. I personally use a manual tool because it is inexpensive and yields very reliable results.

Here is a step-by-step description of wire-wrapping:

### 1. Strip off about a half-inch of insulation

from the end of the spool of wire.

2. Measure | the | point-to-point | length
needed, keeping in mind an extra half-inch plus some slop.

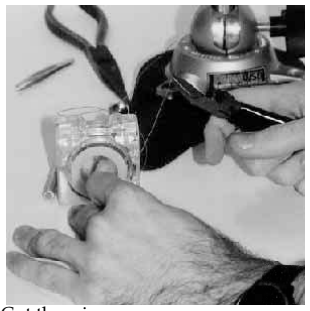
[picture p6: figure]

3. Mark the length with your fingernail. 4. Cut the wire.

### 5. Strip off a half-inch of insulation from

the other end using some needle nose pliers.

### 6. Place the wire in the special slot in the

tool with about an eighth-inch of insulation inside of the tool. Bend the wire at a right angle at the tip of the tool.

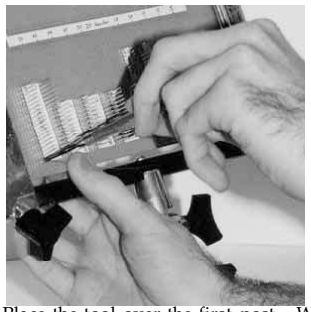
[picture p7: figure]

### 7. Place the tool over the first post. With

the forefinger of your free hand, hold the socket to the board and with your thumb, hold the wire taught. Turn the tool in one direction until all of the bare wire is spun onto the post.
Now, while holding the socket, give the turns a push with the tool. This will eliminate the gap between the turns and the board, mechanically holding the socket firmly to the board.

### 8. Place the free end of the wire into the

tool the same way as before, with about an eighth-inch of insulation inside of the tool.

### 9. Place the tool over the destination post

and pull the wire taught with some pliers. Be careful not to break the wire.

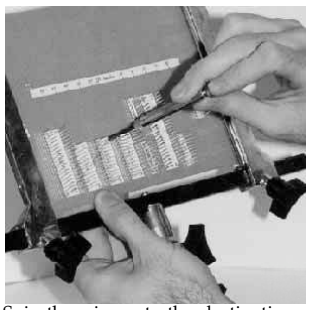
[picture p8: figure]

### 10. Spin the wire onto the destination post

and give it a press when your done.

11. This is the end result.

To correct a mistake, you can spin the tool in the opposite direction which removes the wire. Be careful though not to inadvertently unwrap any wires underneath.

Here are some handy tips to follow when wire-wrapping:

- There should be about 1 turn of insulation and about 4 turns of bare wire wrapped around a post.
- While spinning wires onto a post, be sure not to oppose the direction of wires already tied there.
- Try not to tie too many wires to a single post. Four connections to a single post is about the limit while two connections is the average.
- A nice straight connection usually works best. It may take a few trys to thread the wire to its destination. Tweezers help for doing this.
- Try not to force the tool when you are spinning it because the wire may break and you will have to start over. With a little practice, you will find that a light touch works best.
- When wiring the discrete components, cut the leads to about 1/2 inch long.
- Be careful not to twist and break the leads of a discrete component.
- Do not solder the chip connections! Soldered wire-wrap connections are impossible to remove if a mistake has to be corrected or if a repair is needed. The wire-wrap connection alone is strong enough to last 10-20 years.
- Do not cut the wire wrapping pins if you can help it. Again, corrections and modifications are easier to make if you leave the posts intact.

- Do solder the discrete component connections. Discrete component connections usually require some soldering since the leads are rounded, unlike the rectangular wire-wrapping posts. As a result, there are no edges for a wire to grip on to. A 15 watt soldering iron with a small tip does a good job in this case.
- Don’t ruin your eyes. Use a magnifying glass and good lighting when you work

Wire-wrapping can be a juggling act at times, but you will get used to it and come across many tricks and shortcuts as you progress.

### 3.4.5 Wiring the Board

Now it’s time to do some wiring. While you are wiring the computer, you will have to refer to the schematic diagram in Appendix 3. The schematic diagram depicts all of the connections that must be made. It will be helpful to mark the connections on the schematic with a red pencil as you wire them.

Before wiring, cut the leads of the discrete components to be 1/2 inch long.

Here is a step-by-step description of the wiring:

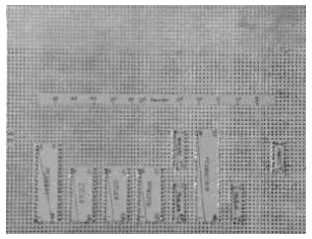
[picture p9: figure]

### 1. Wire the Bypass Capacitors - Wire a 0.1µF tantalum bypass capacitor to

the power connections of all nine chips. The power connections for each chip are listed in the table on the schematic diagram. The bypass capacitors will help filter switching transients from the power lines. Since the tantalum capacitors are polarized, be sure to wire the plus lead to the Vcc connection and the other lead to ground.

When you spin the wire around each lead, be extra careful not to twist and break the lead off. Also, the connection to the capacitor won’t be as good as the connection to the chip since the leads on the capacitor are round with no edges for the wire to grip on to. When we’re done with the whole computer and see it working, we can solder the capacitor connections for extra reliability. For now though, don’t solder anything just in case you need to make corrections.

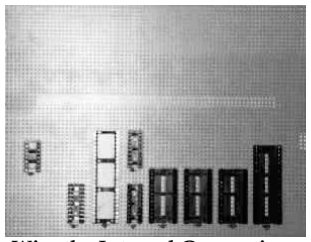
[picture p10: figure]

### 2. Wire the Internal Connections - The internal connections in this case are the

leads which are grounded or pulled high. The 74HC373, the PAL16L8, the 27C64s, the HM62256 and the MAX232 all have internal connections.

### 3. Wire the Multiplexed Address/Data Bus - These are the lines labeled AD0

through AD7 which connect the MC68HC11 to the 74HC245 and 74HC373.

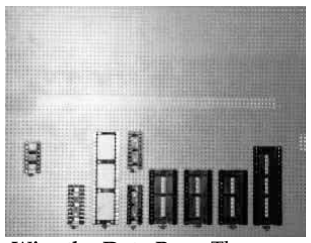
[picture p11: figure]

### 4. Wire the Data Bus - These are the lines labeled D0 through D7. The Data

Bus connects the 74HC373 to the 27C64s the HM62256 and the MC68B21.

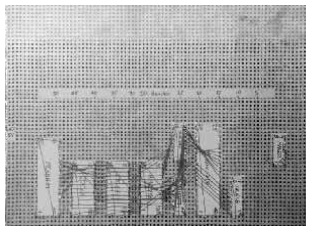
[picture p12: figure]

### 5. Wire the Address Bus - These are the lines labeled A0 through A15. The

lines A0 through A7 originate with the 74HC373 and go to the 27C64s the HM62256 and the MC68B21, while the lines A8 through A15 originate with the MC68HC11 and go to the 27C64s the HM62256 and the PAL16L8.

6. Wire the Control Bus - The signals in the control bus include *RESET, AS, E, R/*W, *BOOT, *SPARE, *RAM and *PIA1.

### 7. Wire the 4.7kΩ Resistor Pack - These connections go to the MC68HC11. Be

careful, the pins are short and fragile. We’ll solder the connections later. The pin with the dot above it is the common which goes to Vcc. You can use tweezers to manually wrap the wires to the resistor pack. Alternately, you can wire the pins first, then thread the wires through the board. In that case, you may need to drill the holes out a little.

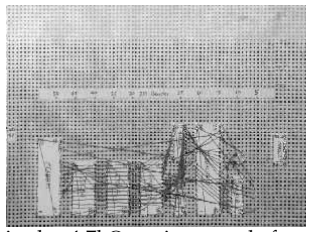
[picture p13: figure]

### 8. Wire the Reset Circuit - Use a resistor in the 4.7kΩ resistor pack for the

pull-up resistor. A bead of solder on each pin of the push-button will mechanically secure it to the board. Be careful not to burn any of the wires.

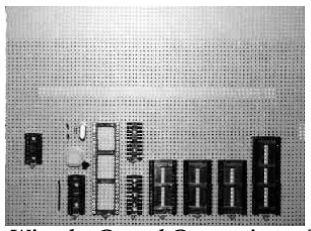
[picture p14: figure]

### 9. Wire the Crystal Connections - This includes wiring Y1, R2, C11 and C12 to

the MC68HC11.

### 10. Wire the J4 jumper - Cut off a 3x1 section of the header connector. Unbend

the right-angle pins so that they are straight. This will give us some extra long pins to wire wrap to.

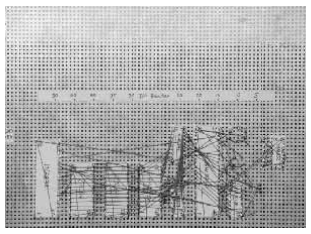
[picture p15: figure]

### 11. Wire the MAX232 - Wire the capacitors to the MAX232 and wire the

MAX232 to the micro.

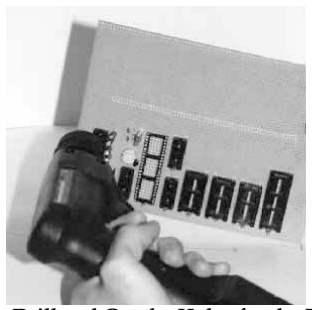
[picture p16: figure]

### 12. Drill and Cut the Holes for the DB-9 Connector - Since the row of five pins

on the connector aren’t aligned with the perfboard, we need to cut a slot for them. Also, drill out the two mounting holes.

### 13. Mount and Wire the DB-9 Connector - Connect the DCD, DSR, CTS and DTR

lines together. Also, prewire the TxD, RxD and GND lines with some wire of an appropriate length. Now thread the three loose wires through the perfboard, screw the DB-9 connector to the perfboard and wire the connector to the MAX232.

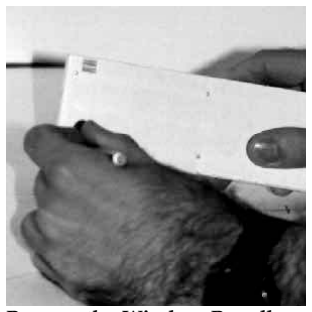
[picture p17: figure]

### 14. Prepare the Wireless Breadboard - Cut off two small rectangles of the foam

backing of the wireless breadboard behind the top and bottom power strips. Four metal strips should be exposed, two on the top and two on the bottom. We will use these openings to wire power directly to the bread board. The photograph in Step 15 shows the recommended orientation for the holes.

One thing to keep in mind is that the power strips on the breadboard are actually divided in half. In other words, the strips don’t connect all the way across. An easy solution is to put small jumper wires in the top of the board.

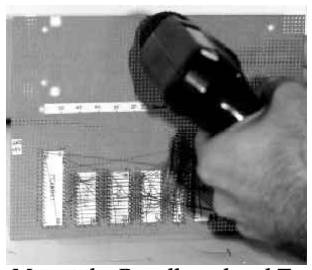
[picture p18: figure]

### 15. Mount the Breadboard and Terminal Strip - Drill all the mounting holes for

the solderless breadboard and the terminal strip. Also, drill and cut the two holes for the power connections to the breadboard. Screw on the breadboard and terminal strip.

### 16. Wire the Terminal Strip - The connections to the terminal strip are

arbitrary. A recommended series of signals to bring out is listed on the label in Appendix 4.

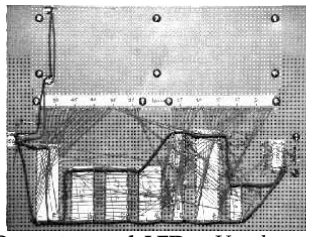
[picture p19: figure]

### 17. Wire the Power Connections , Power Connector and LED - Use heavier

gauge wire for the power busses. Wire the power busses on the breadboard. You might want to paint the power busses on the breadboard so that you remember the polarity.

The final step in construction is to solder the discrete components. Using a 15W iron with a small tip, place a small bead of solder on the discrete component connections. After soldering the discrete components, you can cut their leads shorter. Again, do not cut or solder the chip sockets. It’s a good idea that you wait before doing any soldering until after the testing stage when you are sure that the computer is working.

Additionally, it would be a good idea to add some standoffs to the corners of the board. Machine screws work good for this purpose. Alternatively, you can mount it in a box to protect the wiring. You might want to hold off on mounting the computer until after the computer is tested out though.

Wow! That was a lot of work! Now it’s time to test the computer out.

### 4 Testing the Computer

Now let’s test the computer and see if it works. The testing stage is an opportunity where you can learn the most, so try not to get frustrated i f everything doesn’t work the first time. Every problem that you face can be conquered with a little patience and the success will be rewarding and educational. Turn on your detective skills. The process of elimination will illuminate many hidden problems.

While you are testing, check for obvious errors. For example, go through and double check your connections with a continuity tester. Sometimes a broken or shorted connection is not visible to the naked eye. Remember, a single miswired connection can have bad effects. Here is a common sense checklist to keep in mind during the testing:

- Is the power on? Check the power light.
- Is the power supply set to +5 VDC? Be careful not to supply a high voltage to the computer because that will damage the chips. On the other hand, i f the power supply voltage is too low (<4 V) the LVI chip will activate holding the computer in a Reset state.
- Are any chips loose? Check to make certain that each chip is firmly plugged in.
- Is a pin bent under? Sometimes a chip’s pin can be bent underneath when inserting the chip into its socket causing the pin not to make contact.
- Is a chip plugged in backwards or wired backwards?

Here is a step-by-step procedure for testing the computer:

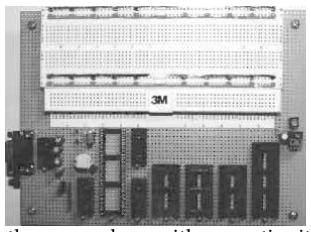
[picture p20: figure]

### 1. Check for shorts in the power buss with a continuity meter. If you use an

ohmmeter to check for continuity, keep in mind that the filter capacitors will charge up giving you a changing reading. Now hook up a +5 VDC power supply to the computer. With no chips installed, power the computer and check each socket for power with a voltmeter. Make certain that you read +5 VDC at the correct polarity.

Vcc

330 Ω
PA7

PA6

PA5

PA4

PA3

2. Turn off the power and plug in the MC68HC11, the Test ROM, the 74HC373, the 74HC245 and the PAL16L8. The Test ROM should be plugged into the

Boot ROM socket. Also, wire five LEDs to PA3 through PA7 of the MC68HC11.

It’s time to perform a smoke test. A smoke test is simply a test where you turn on the project and check for smoke. After you turn on the computer, feel each chip to make sure that none are getting hot. This could indicate a backwards power connection. Keep one hand on the power switch and be ready to turn off the power at the first sign of trouble.

Now check the LEDs. Are they blinking? Is the program running? If not, it’s time to do some troubleshooting.

- Is the EPROM programmed properly?
- Is the PAL programmed properly?
- Is the crystal oscillator running? Check the E clock signal on an oscilloscope and look for a 2 MHz square wave.
- Is the Reset line high? Try pressing the Reset button and see if the program starts running.

### 3. Don’t disconnect the LEDs yet. Turn off the computer and plug in the

MAX232 chip. Power up the computer again and perform another smoke test. Make sure that the MAX232 is not getting hot. Using a voltmeter, check pin 2 of the MAX232, it should be +10 VDC with respect to ground. Now check pin 6, it should be -10 VDC with respect to ground. Also, make certain that the test program is still running.

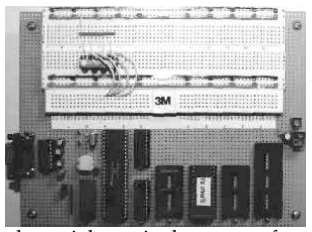
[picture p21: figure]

4. For this step you need a serial terminal program for your personal computer. Turn off the project, remove the Test ROM and plug the BUFFALO ROM in its place (don’t plug the ROM in backwards). Also, make certain that the J4 jumper is grounded.

Hook up the computer to the serial port on your personal computer. Set the serial terminal program to 9600 Baud, 8 Data Bits, No Parity, 1 Stop B i t and No Handshaking.

Now power up the computer and perform another smoke test. Did you get a BUFFALO prompt similar to the one below? Try hitting the Return key on your personal computer.

BUFFALO 3.4 (ext) - Bit User Fast Friendly Aid to Logical Operation

If nothing happened then:

- Is the DB-9 connector wired properly?
- Do you see a data transmission every time you hit the Reset switch? You can check for this by placing an oscilloscope on the transmit pins, 10 and 7 of the MAX232 and pin 43 of the MC68HC11.
- Did you plug in the right ROM (BUFFALO)?
- Are you connected to the correct serial port on your personal computer?
- Do you have a good connection between the two computers?
5. Turn off the computer and plug the Test ROM into the Extra ROM socket. Turn the computer back on and perform another smoke test. Now from BUFFALO type: go C000 [ENTER]. Are the LEDs blinking? To stop the program press the Reset button. Now, try disassembling the test program. Type: asm C000 [ENTER]. Hit [ENTER] to advance to the next line. To exit the disassembler type: [Control-A].

### 6. Turn off the computer and plug in the HM62256. Turn the computer on and

perform the smoke test as usual. Using the BUFFALO Block Fill command, try to write to locations in the RAM. Type: bf 7000 7100 AA [ENTER]. Now type: md 7000 [ENTER]. Were you successful writing to the RAM? Also, try running the test program. Is it still working?

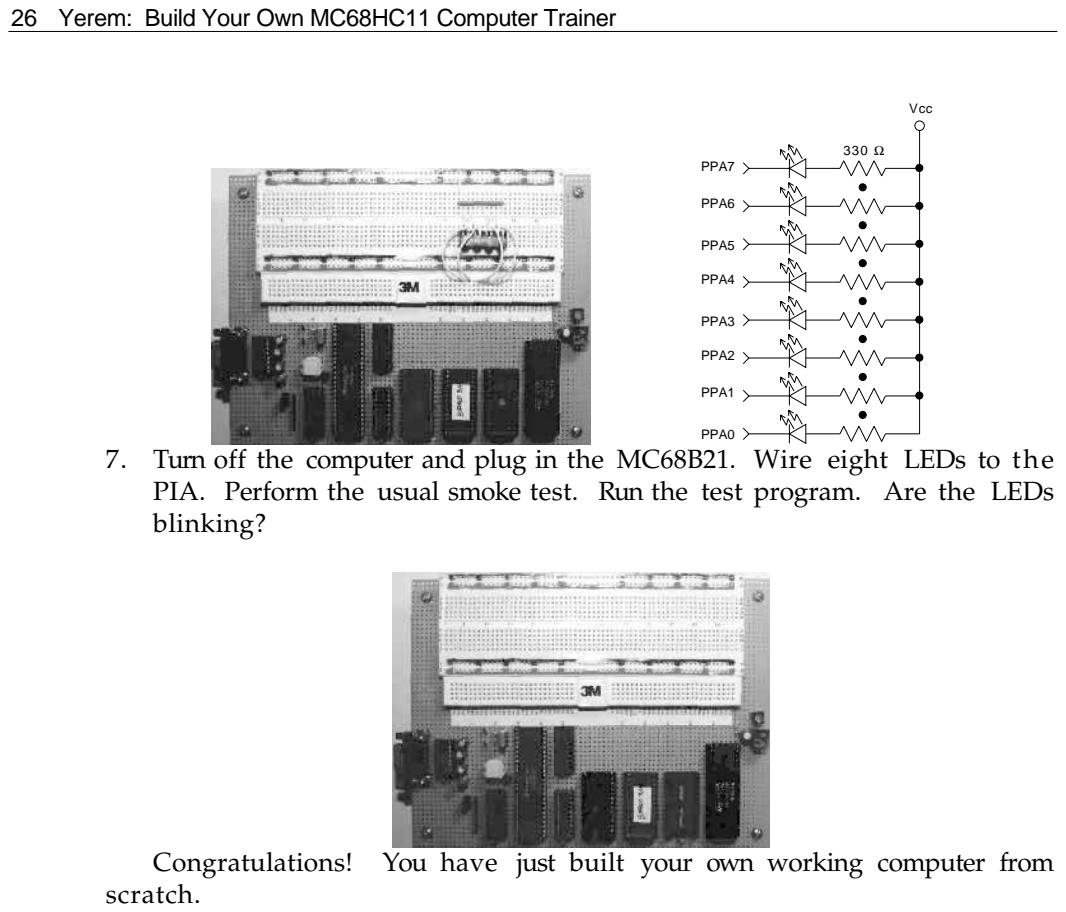
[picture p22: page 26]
Vcc; PPA7; PPA6; PPA5; PPA4; PPA3; PPA2; PPA1; PPA0

7. Turn off the computer and plug in the MC68B21. Wire eight LEDs to the
PIA. Perform the usual smoke test. Run the test program. Are the LEDs
blinking?

Congratulations! You have just built your own working computer from
scratch.

### 5 Using the Computer

Now that the computer is finished you can start putting it to use. This section will describe what is required to program your new computer.

In addition to reading this section, read through the MC68HC11A1 data book, the MC6821 data sheet and the M68HC11EVB Evaluation Board user’s manual. These documents cover a lot of information not dealt with here.

Our computer was designed to be similar to the Motorola MC68HC11 Evaluation Board (EVB) which you may be familiar with. Nonetheless, our board has many differences from the EVB, so keep this in mind when you are programming. This section will cover what those differences are.

### 5.1 Programming

When you are programming your computer, the most important thing to be aware of is the memory map. The Chip Select PAL divides up the 64 k B memory space among the external memory and peripherals while the MC68HC11 handles the addressing of its internal devices. When there is an address space conflict between the internal and external devices, the internal devices have priority. In the memory map drawn below, you can see that the internal RAM and Control Registers overlap the 32 kB of external RAM.

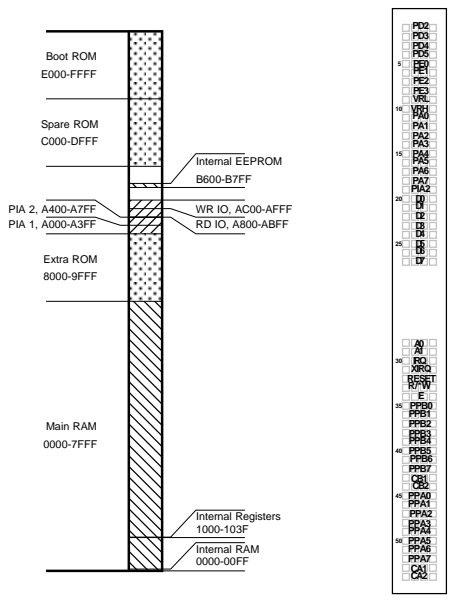
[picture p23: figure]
PD2 PD3 PD4 PD5 PE0 PE1 PE2 PE3 VRL VRH PA0 PA1 PA2 PA3 PA4 PA5 PA6 PA7 PIA2 D0 D1 D2 D3 D4 D5 D6 D7; A0 A1 IRQ XIRQ RESET R/*W E PPB0 PPB1 PPB2 PPB3 PPB4 PPB5 PPB6 PPB7 CB1 CB2 PPA0 PPA1 PPA2 PPA3 PPA4 PPA5 PPA6 PPA7 CA1 CA2; Internal RAM 0000-00FF; Internal Registers 1000-103F; Main RAM 0000-7FFF; Extra ROM 8000-9FFF; PIA 1, A000-A3FF; RD IO, A800-ABFF; PIA 2, A400-A7FF; WR IO, AC00-AFFF; Internal EEPROM B600-B7FF; Spare ROM C000-DFFF; Boot ROM E000-FFFF

Use this memory map to plan the organization of any hardware and software that you add to the computer.

The MC68HC11 has a large number of on-chip peripherals to take advantage of. The MC68HC11 data book describes how to program the on-chip peripherals.

### 5.1.1 Using BUFFALO

The BUFFALO monitor program will allow you to do most of your program development. In BUFFALO you can view and modify memory and registers, assemble and disassemble programs, and perform advanced debugging. The most important feature of BUFFALO is its Load command. It allows you to download Motorola Hex (.s19) files to the computer’s RAM through the serial port. Here is a procedure for using BUFFALO in your program development:

1. Write the source code.

### 2. Give the source code a base address somewhere in the RAM’s address

space between $0000 - $7FFF (watch out for the MC68HC11’s Control Registers).
3. Cross-compile your program as an .s19 file.

### 4. At the BUFFALO prompt, type: load t [ENTER]. Now BUFFALO

will wait to receive a .s19 byte stream over the serial port. Use your terminal emulator program to send the .s19 text file to BUFFALO.

### 5. If everything goes well, BUFFALO will print the message: done and

provide the command prompt again.
6. You can now run your program by using the go command.

If you forget a command in BUFFALO, typing: help [ENTER] will display the list of commands. The EVB manual has detailed descriptions of the other BUFFALO commands.

### 5.1.2 Programming Your Own ROMs

You can write your program to fit in a boot ROM. First you have to place the program in the space between $E000 - $FFFF and place a jump vector to your program in the address $FFFE. When your new ROM is programmed you must physically remove the BUFFALO ROM and replace it with your new ROM. Subsequently, your new program will run every time the computer is turned on.

Alternately, you can use the Spare ROM socket for your program. In this case you must place your program within the space $C000 - $DFFF. This time though, you won’t be able to modify the Reset jump vector to jump to your program. You can either run your program from the BUFFALO prompt, or pull the J4 jumper high to tell BUFFALO to jump to the first location of the MC68HC11’s internal EEPROM at $B600. Then you simply need to put a jump instruction at $B600 to call your new program. Keep in mind that the Spare ROM socket is for your use and can be left empty most of the time.

Most of the time though, you will be loading your program into the computer’s RAM and executing the program from there. The advantage of this is that you will be able to rapidly change your program and try it out. The disadvantage is that the program will disappear when the computer is turned off.

### 5.2 Interfacing

In order to keep the design practical certain built-in resources of the MC68HC11 aren’t available on our computer. For example, in this design the pins PD0 and PD1 are used for the serial port and as a result aren’t readily available for use as digital I/O. Also, since the BUFFALO monitor program uses PE0 as an input for the J4 jumper, PE0 shouldn’t be used for other purposes. Additionally, lines PE4 through PE7 of Port E aren’t pinned out on the MC68HC11A1P version used in this design. This is because the DIP (Dual Inline Package) version of the MC68HC11A1 used here doesn’t have enough pins to accommodate all of Port E. The pins PE4 through PE7 are only available on the PLCC (Plastic Leaded Chip Carrier) version. The PLCC version wasn’t used for this project because i t would have been harder to wire by hand. Finally, Port B, Port C, STRA and STRB are unavailable because we are operating the MC68HC11 in expanded mode as opposed to single chip mode. Expanded mode is what allows us to connect external memory like the HM62256 RAM chip and the 27C64 EPROM chip to the microprocessor.

Despite these limitations, expanded mode allows us to add as much I/O to the computer as we require, albeit with a few extra chips required. In this design, the MC68B21 chip augments the available digital I/O. The following sections will describe how to use the MC68B21 and how add even more digital I/O to the design.

### 5.2.1 How to use the MC6821

The MC6821 Peripheral Interface Adapter (PIA) chip provides bi-directional digital I/O for the 6800 family of microprocessors with a minimum of fuss. The MC6821 has two bi-directional 8-bit data ports along with two handshaking control lines for each port. The handshaking lines allow each port to be used as

Internally, the MC6821 has six registers for operating the chip, three registers for Port A and three registers for Port B. When RS1=0 the Port A register set is selected and when RS1=1 the Port B registers are selected. When RS0=1 the Control Register for the given port is selected. When RS0=0 the register that is accessed depends on bit 2, the DDR Access Bit, of the Control Register. If the DDR Access Bit is 0, the Data Direction Register is selected. I f the DDR Access Bit is 1, the Peripheral I/O Register is selected.

The MC6821 Control Register
b7 | b6 | b5 | b4 | b3 | b2 | b1 | b0
IRQ A(B) 1 Flag | IRQ A(B) 2 Flag | CA2 (CB2) Control | | | DDR Access | CA1 (CB1) Control

The Data Direction Register for each port allows any of the lines on a port to be configured as inputs or outputs. A zero bit will configure a line as an input while a one bit will configure the line as an output. Similarly, the Peripheral I/O Register allows you to read from and write to the I/O ports.

A simple procedure for programming a port on the MC6821 is to:

1. Set the DDR Access Bit in the Control Register to 0.
2. Program the Data Direction Register.
3. Set the DDR Access Bit in the Control Register to 1.
4. Access the Peripheral I/O Register to read and write the I/O port.

This procedure applies for both Port A and Port B. Once you have programmed the Data Direction Register, you probably will want to leave the DDR Access Bit set to 1 for the rest of the program.

Here is a code snippet which demonstrates how to program the MC6821:

clr $A001 | Set the DDRA Access Bit to 0.
clr $A003 | Set the DDRB Access Bit to 0.
ldaa #FF
staa $A000 Set all bits on Port A to output.
ldaa #0F
staa $A002 Set upper bits of Port B to input and lower bits to output. ldaa #04
staa $A001 | Set the DDRA Access Bit to 1.
staa $A003 | Set the DDRB Access Bit to 1.
ldaa #FF
staa $A000 | Turn on all of the bits on Port A.
ldaa $A002 | Read Port B.

Check the MC6821 data sheet to find out how to use its more advanced features.

### 5.2.2 Adding a Basic Input Port

If you need digital inputs, the following one chip circuit will do the job,

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
74HC244

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
Data Bus

Control Bus

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
19 | Vcc - Pin 20 Gnd - Pin 10

14
16

5
7
9

18

*RDIO ($A800)

To read the current state of the input lines simply perform a read from the address $A800. The following line of assembly language will read the values of the eight input lines into the A register:

ldaa $A800

This circuit can apply to other type of digital input that you would want to connect to the computer, such as an analog-to-digital converter.

### 5.2.3 Adding a Basic Output Port

Here is a circuit similar to the previous one which provides eight digital outputs to the computer,

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
74HC273

D1

D2

D3

D4

D5

D6

D7

*CLR
CLK

D0

*WRIO

# *RESET Data Bus

Control Bus

Out0

Out1

Out2

Out3

Out4

Out5

Out6

Out7

1
11

Vcc - Pin 20
Gnd - Pin 10

A simple write to the address $AC00 will change the states of the outputs. The following two lines of assembly language show how to do this:

ldaa #AA
staa $AC00

You can of course use this circuit as an example for connecting other types of output devices to the computer.

### 5.2.4 Adding More PIAs

If you require more sophisticated I/O, you can add more PIAs to the computer. Simply plug the new PIA into the breadboard and wire it directly to the data bus through the terminal strip. The only difference between the second PIA and the original one is that the *CS2 pin of the new PIA is connected to the *PIA2 signal. This means that the base address of the new PIA begins at $A400 instead of $A000.

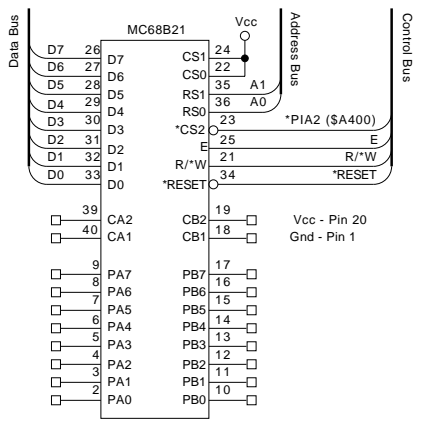
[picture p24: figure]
E R/*W *RESET; Vcc; Data Bus; Address Bus; Control Bus; *PIA2 ($A400); Vcc - Pin 20 Gnd - Pin 1

Now you have two extra bi-directional ports to work with. Similarly, you can add as many PIAs to the computer as you need, keeping in mind that there are only a finite number of unused address locations available.

### 6 Conclusion

I hope this was a great learning experience for you. When I built my first computer it was pretty frustrating. Part of the frustration was due to the complexity of the computer and part was due to errors in the instructions. I hope that I’ve at least eliminated those two variables for you. Nonetheless, after a lot of struggling I was able to get the computer working and learned a lot in the process.

I’m sure you will get much use out of your new computer and I know there will be more home-built computers in your future. Just think, ten years from now you will look back fondly to this experience.

### References

[1] Ciarcia, Steve and Burt Brown. “Using the Motorola MC68HC11.” Circuit Cellar INK 18 (1990): 36-48.
[2] Farmer, Brian. “Planting Geraniums by Robot/Build an MC68HC11-based 2-D Sensor.” Circuit Cellar INK 29 (1992): 12-21.
[3] Greenfield, Joseph D. The 68HC11 Microcontroller. Orlando, FL: Saunders College Publishing, 1992.
[4] Motorola Inc. MC68HC11A8 Technical Data Book (Lit. No. MC68HC11A8/D). Phoenix, AZ: Motorola Inc., 1991.
[5] Motorola Inc. MC6821 Peripheral Interface Adapter Data Sheet (Lit. No. MC6821/D). Phoenix, AZ: Motorola Inc., 1985.
[6] Motorola Inc. M68HC11EVB Evaluation Board User’s Manual (Lit. No. M68HC11EVB/D1). Phoenix, AZ: Motorola Inc., 1986.
[7] Olney, Bruce L. “Inexpensive 68HC11 Cross-development.” Circuit Cellar INK 44 (1994): 22-29.
[8] Swiger, Frank and Joe Glover. “The FS-100 MC68HC11-Based Single-Board Computer.” Circuit Cellar INK 24 (1991): 52-59.

### Appendix 1 - Master Parts List

This is the master parts list for the prototype computer that was built. The quantity, manufacturer, manufacturer part number and general description is shown. Specific manufacturers aren't listed for easy to find generic parts.

# | | Part Description | Part No. | Manufacturer

1 | U1 | 8-bit HCMOS MCU | MC68HC11A1P | Motorola
1 | U2 | PIA 2 MHz | MC68B21 | Motorola
1 | U3 | Octal Tri-State D Type Latch | 74HC373
1 | U4 | Octal Tri-State Transceiver | 74HC245
1 | U5 | PAL 16L8B 15ns | 16L8B
2 | U6, U7 | 8kx8 ≤250ns EPROM | 27C64-250
1 | U8 | 32kx8 ≤250ns Static RAM | HM62256LP-10
1 | U9 | +5V Powered Dual RS-232 Trans./Rcvr. | MAX232CPE | Maxim
1 | U10 | 3.8V O.D. Low Voltage Detector | MN13811-Q | Panasonic
1 | Y1 | 8.0 MHz Crystal
1 | RP1 | 4.7 kΩ SIP 7 Resistor Network
1 | R1 | 330 Ω 1/4 W Resistor
1 | R2 | 10 MΩ 1/4 W Resistor
1 | C1 | 100 µF Radial Electrolytic Capacitor
4 | C13-C16 | 10 µF Radial Electrolytic Capacitor
2 | C11, C12 | 22 pF Ceramic Capacitor
9 | C2-C9 | 0.1 µF Tantalum Capacitor

### 1 Right Angle PC Mount Female DB-9 Connector

1 | J4 | Shorting Jumper Block
1 | J4 | 1x3 WW Header Pins

1 16-Pin DIP WW Socket 3-Level 3 20-Pin DIP WW Socket 3-Level
3 28-Pin DIP WW Socket 3-Level
1 40-Pin DIP WW Socket 3-Level
1 | | 48-Pin DIP WW Socket 3-Level | 123-93-648-41-001 | Mill-Max
1 | LED1 | PC Board Mount Green LED With Holder | 5381H5 | Industrial Devices, Inc.
1 | | SPST Momentary Square Yellow Pushbutton | 520-01-2 | E-Switch
1 | | 2 Position Terminal Block | ED1609 | On-Shore Technology, Inc.
1 | | 6"x8” IC-Spacing Perfboard | 276-1396 | Radio Shack
1 | | 6.5" Solderless Breadboard w/Power Busses | 923252 | 3M
1 | | 54 Point Terminal Strip with Solder Tails | 923292 | 3M
1 | | Male-Female DB-9 Cable (2m) | AK131-2 | Assmann

### 1 Wrapping Wire, 50’ Spool

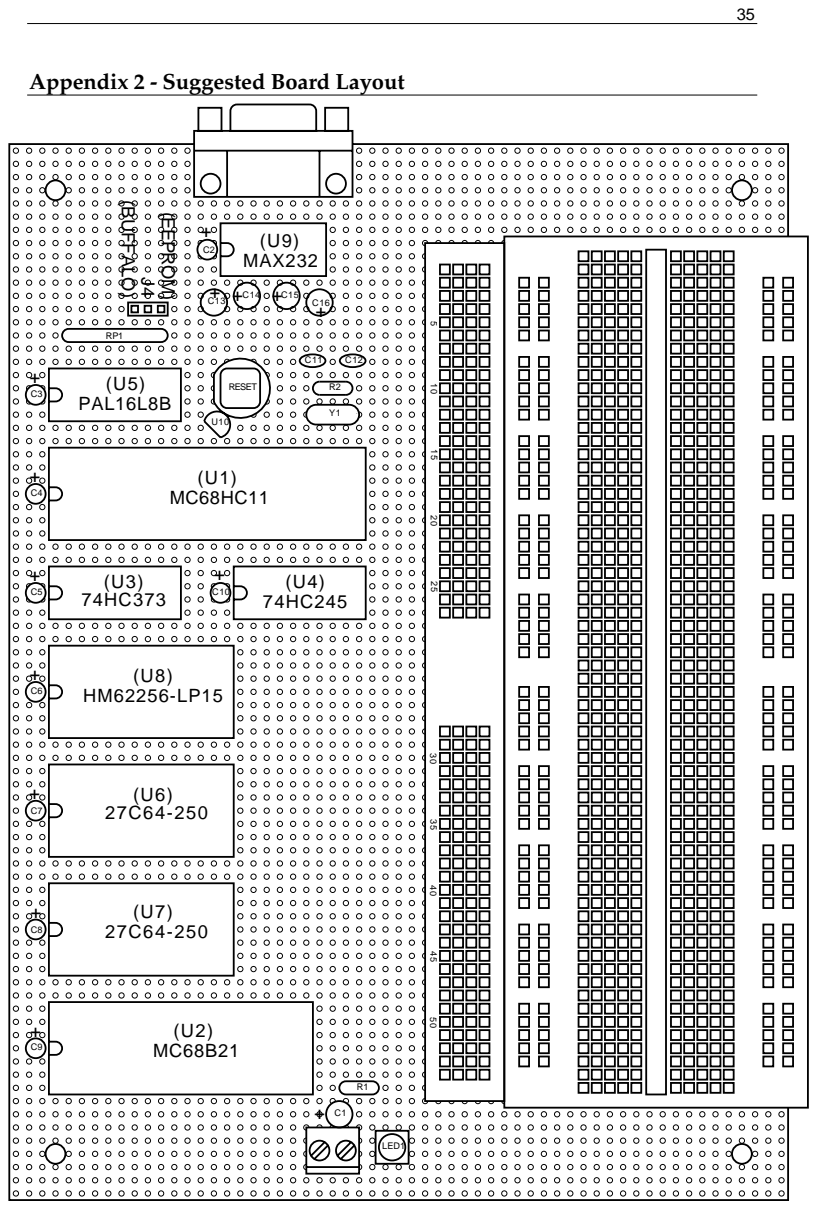
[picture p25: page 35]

Appendix 2 - Suggested Board Layout

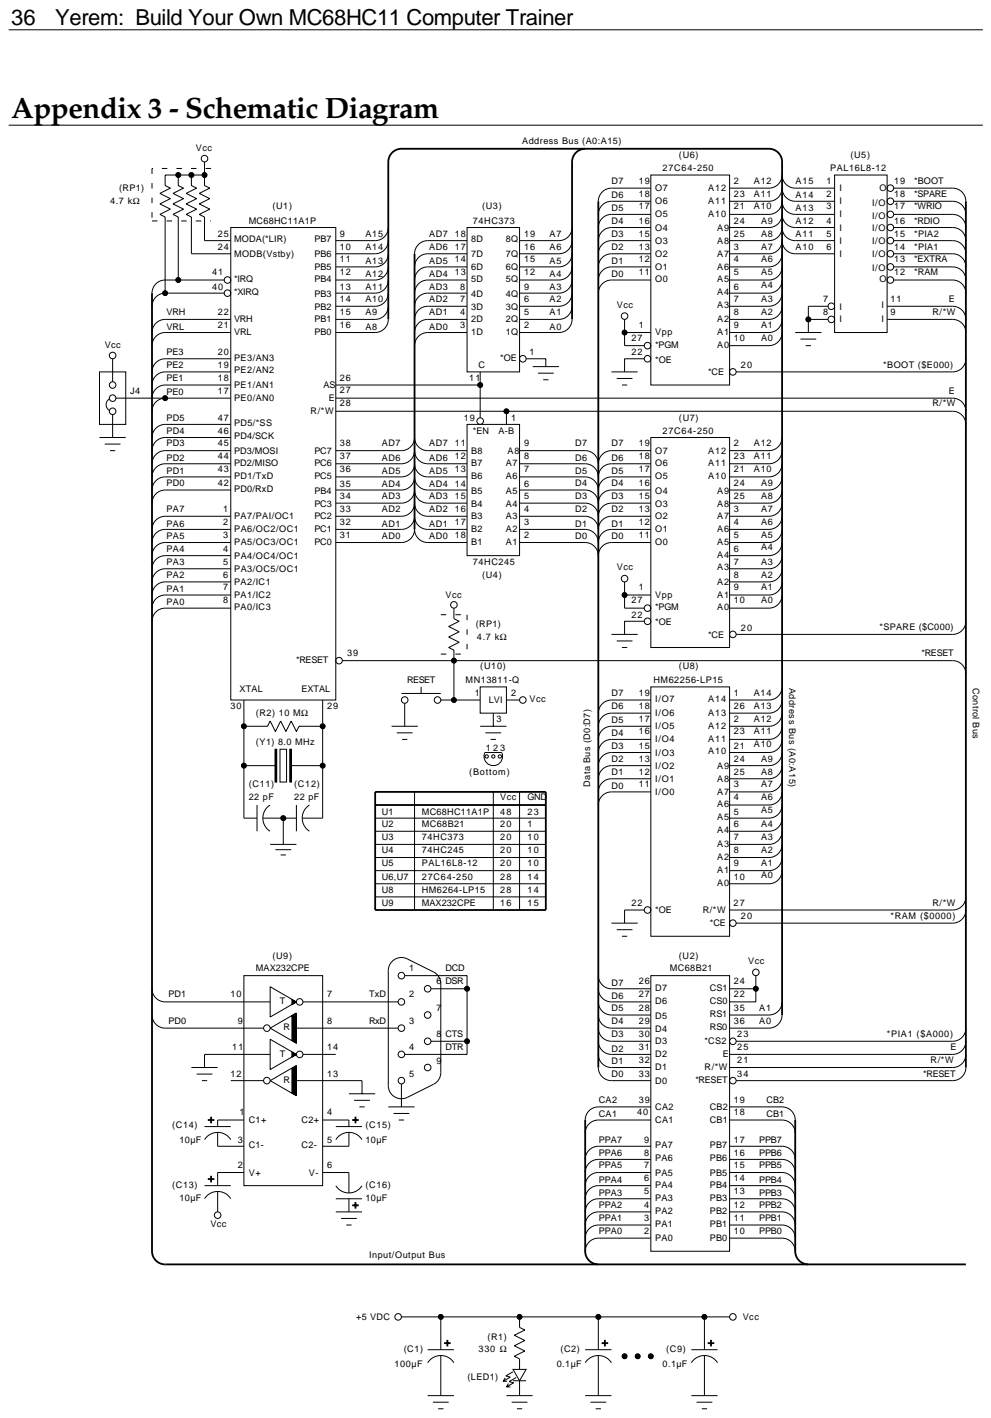
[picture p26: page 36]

U2 | MC68B21 20 1
U3 | 74HC373 20 10
U4 | 74HC245 20 10
U5 | PAL16L8-12 20 10
U6,U7 | 27C64-250 28 14
U8 | HM6264-LP15 28 14
U9 | MAX232CPE 16 15

### Appendix 4 - Wire Wrapping Labels

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
PIA2

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
XIRQ

RESET

R/*W

E

PPB0

PPB1

PPB2

PPB3

PPB4

PPB5

PPB6

PPB7

CB1

CB2

PPA0

PPA1

PPA2

PPA3

PPA4

PPA5

PPA6

PPA7

CA1

CA2

8 | 1
9 | 16
10 | 1
11 | 20

11
10 | 1
| 20

11
10 | 1
| 20
14 | 1
15 | 28
14 | 1
15 | 28
14 | 1
15 | 28

1

1

20

21 | 40

24

25 | 48
MC68HC11A1P

MC68B21

HM62256

27C64

27C64

PAL16L8

74HC373

74HC245

MAX232

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
HEADER

GND

+5V

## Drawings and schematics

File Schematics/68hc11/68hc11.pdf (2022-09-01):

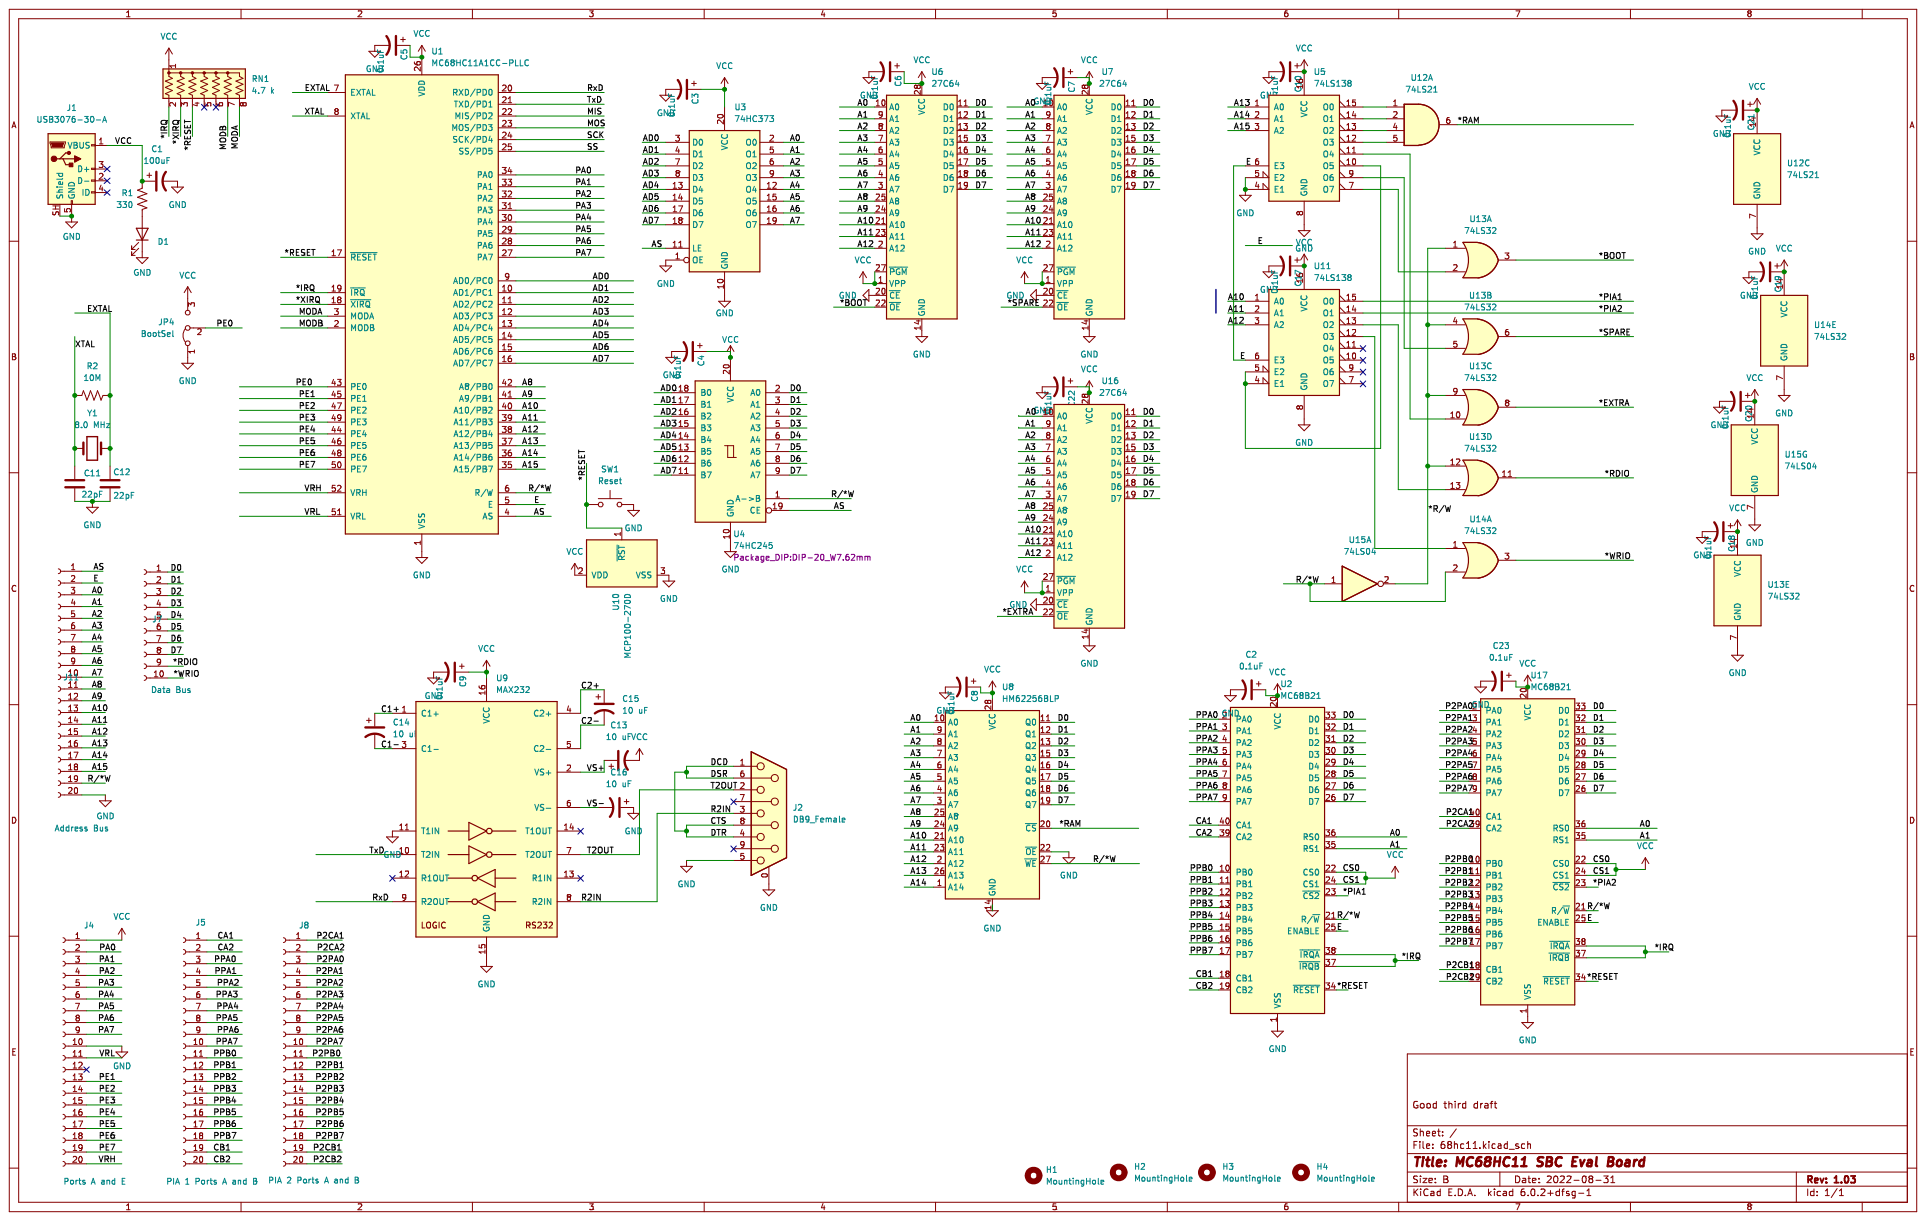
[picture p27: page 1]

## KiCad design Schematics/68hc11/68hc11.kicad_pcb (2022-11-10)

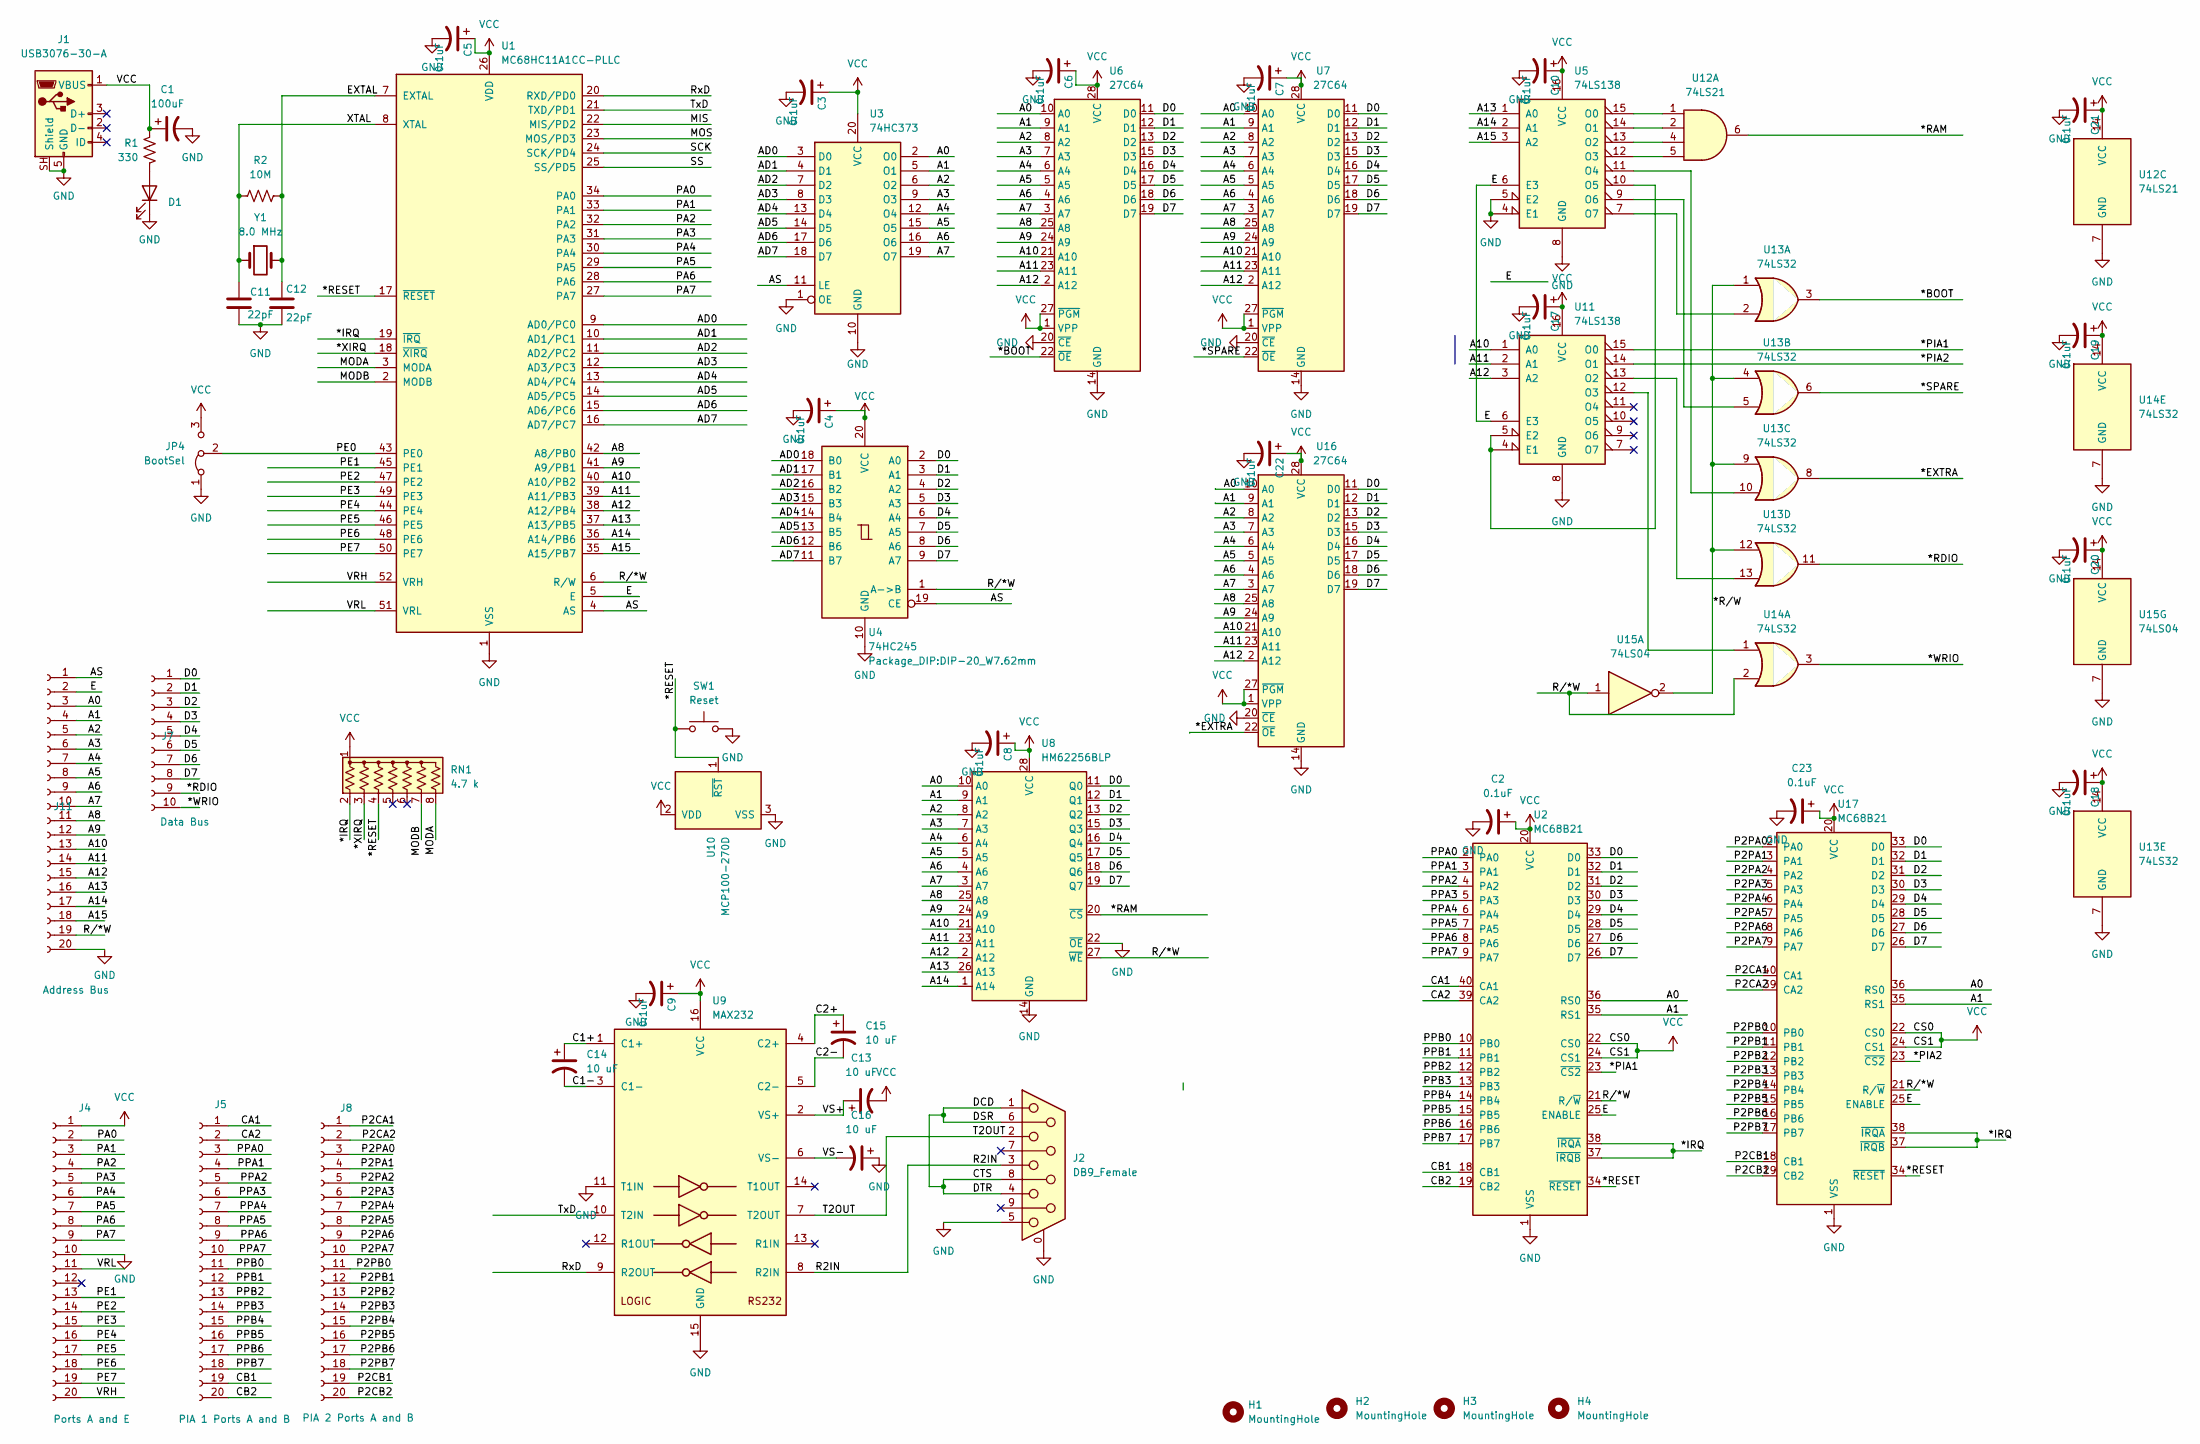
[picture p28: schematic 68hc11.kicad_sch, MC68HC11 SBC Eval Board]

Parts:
C1: 100uF; CP_Radial_D5.0mm_P2.00mm
C2, C3, C4, C5, C6, C7, C8, C9, C10, C17, C18, C19, C20, C21, C22, C23: 0.1uF; C_Disc_D3.0mm_W2.0mm_P2.50mm
C11, C12: 22pF; C_Disc_D3.0mm_W1.6mm_P2.50mm
C13, C14, C15, C16: 10 uF; CP_Radial_D5.0mm_P2.00mm
D1: LED; LED_D5.0mm
H1, H2, H3, H4: MountingHole; MountingHole_2.5mm
J1: USB3076-30-A; USB_Micro_B_Female_10118193-0001LF
J2: DB9_Female; DSUB-9_Male_Horizontal_P2.77x2.84mm_EdgePinOffset4.94mm_Hou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
J4: Ports A and E; PinSocket_1x20_P2.54mm_Vertical
J5: PIA 1 Ports A and B; PinSocket_1x20_P2.54mm_Vertical
J7: Data Bus; PinSocket_1x10_P2.54mm_Vertical
J8: PIA 2 Ports A and B; PinSocket_1x20_P2.54mm_Vertical
J11: Address Bus; PinSocket_1x20_P2.54mm_Vertical
JP4: BootSel; PinHeader_1x03_P2.54mm_Vertical
R1: 330; R_Axial_DIN0204_L3.6mm_D1.6mm_P5.08mm_Horizontal
R2: 10M; R_Axial_DIN0204_L3.6mm_D1.6mm_P5.08mm_Horizontal
RN1: 4.7 k; R_Array_SIP8
SW1: Reset; SW_PUSH_6mm
U1: MC68HC11A1CC-PLLC; PLCC-52_THT-Socket
U2, U17: MC68B21; DIP-40_W15.24mm
U3: 74HC373; DIP-20_W7.62mm
U4: 74HC245; DIP-20_W7.62mm
U5, U11: 74LS138; DIP-16_W7.62mm
U6, U7, U16: 27C64; DIP-28_W15.24mm
U8: HM62256BLP; DIP-28_W15.24mm
U9: MAX232; DIP-16_W7.62mm
U10: MCP100-270D; TO-92
U12: 74LS21; DIP-14_W7.62mm
U13, U14: 74LS32; DIP-14_W7.62mm
U15: 74LS04; DIP-14_W7.62mm
Y1: 8.0 MHz; Crystal_HC49-4H_Vertical

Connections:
/*BOOT: U6.22 (~OE), U13.3
/*EXTRA: U13.8, U16.22 (~OE)
/*IRQ: RN1.2 (R1), U1.19 (~IRQ), U2.37 (~IRQB), U2.38 (~IRQA), U17.37 (~IRQB), U17.38 (~IRQA)
/*PIA1: U2.23 (~CS2), U11.15 (O0)
/*PIA2: U11.14 (O1), U17.23 (~CS2)
/*RAM: U8.20 (~CS), U12.6
/*RDIO: U13.11
/*RESET: RN1.4 (R3), SW1.1, U1.17 (~RESET), U2.34 (~RESET), U10.1 (~RST), U17.34 (~RESET)
/*R/W: U13.1, U13.4, U13.9, U13.12, U15.2
/*SPARE: U7.22 (~OE), U13.6
/*WRIO: U14.3
/*XIRQ: RN1.3 (R2), U1.18 (~XIRQ)
/A0: J11.3, U2.36 (RS0), U3.2 (O0), U6.10 (A0), U7.10 (A0), U8.10 (A0), U16.10 (A0), U17.36 (RS0)
/A1: J11.4, U2.35 (RS1), U3.5 (O1), U6.9 (A1), U7.9 (A1), U8.9 (A1), U16.9 (A1), U17.35 (RS1)
/A2: J11.5, U3.6 (O2), U6.8 (A2), U7.8 (A2), U8.8 (A2), U16.8 (A2)
/A3: J11.6, U3.9 (O3), U6.7 (A3), U7.7 (A3), U8.7 (A3), U16.7 (A3)
/A4: J11.7, U3.12 (O4), U6.6 (A4), U7.6 (A4), U8.6 (A4), U16.6 (A4)
/A5: J11.8, U3.15 (O5), U6.5 (A5), U7.5 (A5), U8.5 (A5), U16.5 (A5)
/A6: J11.9, U3.16 (O6), U6.4 (A6), U7.4 (A6), U8.4 (A6), U16.4 (A6)
/A7: J11.10, U3.19 (O7), U6.3 (A7), U7.3 (A7), U8.3 (A7), U16.3 (A7)
/A8: J11.11, U1.42 (A8/PB0), U6.25 (A8), U7.25 (A8), U8.25 (A8), U16.25 (A8)
/A9: J11.12, U1.41 (A9/PB1), U6.24 (A9), U7.24 (A9), U8.24 (A9), U16.24 (A9)
/A10: J11.13, U1.40 (A10/PB2), U6.21 (A10), U7.21 (A10), U8.21 (A10), U11.1 (A0), U16.21 (A10)
/A11: J11.14, U1.39 (A11/PB3), U6.23 (A11), U7.23 (A11), U8.23 (A11), U11.2 (A1), U16.23 (A11)
/A12: J11.15, U1.38 (A12/PB4), U6.2 (A12), U7.2 (A12), U8.2 (A12), U11.3 (A2), U16.2 (A12)
/A13: J11.16, U1.37 (A13/PB5), U5.1 (A0), U8.26 (A13)
/A14: J11.17, U1.36 (A14/PB6), U5.2 (A1), U8.1 (A14)
/A15: J11.18, U1.35 (A15/PB7), U5.3 (A2)
/AD0: U1.9 (AD0/PC0), U3.3 (D0), U4.18 (B0)
/AD1: U1.10 (AD1/PC1), U3.4 (D1), U4.17 (B1)
/AD2: U1.11 (AD2/PC2), U3.7 (D2), U4.16 (B2)
/AD3: U1.12 (AD3/PC3), U3.8 (D3), U4.15 (B3)
/AD4: U1.13 (AD4/PC4), U3.13 (D4), U4.14 (B4)
/AD5: U1.14 (AD5/PC5), U3.14 (D5), U4.13 (B5)
/AD6: U1.15 (AD6/PC6), U3.17 (D6), U4.12 (B6)
/AD7: U1.16 (AD7/PC7), U3.18 (D7), U4.11 (B7)
/AS: J11.1, U1.4 (AS), U3.11 (LE), U4.19 (CE)
/C1+: C14.1, U9.1 (C1+)
/C1-: C14.2, U9.3 (C1-)
/C2+: C15.1, U9.4 (C2+)
/C2-: C15.2, U9.5 (C2-)
/CA1: J5.1, U2.40 (CA1)
/CA2: J5.2, U2.39 (CA2)
/CB1: J5.19, U2.18 (CB1)
/CB2: J5.20, U2.19 (CB2)
/CTS: J2.1, J2.4, J2.6, J2.8
/D0: J7.1, U2.33 (D0), U4.2 (A0), U6.11 (D0), U7.11 (D0), U8.11 (Q0), U16.11 (D0), U17.33 (D0)
/D1: J7.2, U2.32 (D1), U4.3 (A1), U6.12 (D1), U7.12 (D1), U8.12 (Q1), U16.12 (D1), U17.32 (D1)
/D2: J7.3, U2.31 (D2), U4.4 (A2), U6.13 (D2), U7.13 (D2), U8.13 (Q2), U16.13 (D2), U17.31 (D2)
/D3: J7.4, U2.30 (D3), U4.5 (A3), U6.15 (D3), U7.15 (D3), U8.15 (Q3), U16.15 (D3), U17.30 (D3)
/D4: J7.5, U2.29 (D4), U4.6 (A4), U6.16 (D4), U7.16 (D4), U8.16 (Q4), U16.16 (D4), U17.29 (D4)
/D5: J7.6, U2.28 (D5), U4.7 (A5), U6.17 (D5), U7.17 (D5), U8.17 (Q5), U16.17 (D5), U17.28 (D5)
/D6: J7.7, U2.27 (D6), U4.8 (A6), U6.18 (D6), U7.18 (D6), U8.18 (Q6), U16.18 (D6), U17.27 (D6)
/D7: J7.8, U2.26 (D7), U4.9 (A7), U6.19 (D7), U7.19 (D7), U8.19 (Q7), U16.19 (D7), U17.26 (D7)
/E: J11.2, U1.5 (E), U2.25 (ENABLE), U5.6 (E3), U11.6 (E3), U17.25 (ENABLE)
/EXTAL: C12.1, R2.1, U1.7 (EXTAL), Y1.2
/MIS: U1.22 (MIS/PD2)
/MODA: RN1.8 (R7), U1.3 (MODA)
/MODB: RN1.7 (R6), U1.2 (MODB)
/MOS: U1.23 (MOS/PD3)
/P2CA1: J8.1, U17.40 (CA1)
/P2CA2: J8.2, U17.39 (CA2)
/P2CB1: J8.19, U17.18 (CB1)
/P2CB2: J8.20, U17.19 (CB2)
/P2PA0: J8.3, U17.2 (PA0)
/P2PA1: J8.4, U17.3 (PA1)
/P2PA2: J8.5, U17.4 (PA2)
/P2PA3: J8.6, U17.5 (PA3)
/P2PA4: J8.7, U17.6 (PA4)
/P2PA5: J8.8, U17.7 (PA5)
/P2PA6: J8.9, U17.8 (PA6)
/P2PA7: J8.10, U17.9 (PA7)
/P2PB0: J8.11, U17.10 (PB0)
/P2PB1: J8.12, U17.11 (PB1)
/P2PB2: J8.13, U17.12 (PB2)
/P2PB3: J8.14, U17.13 (PB3)
/P2PB4: J8.15, U17.14 (PB4)
/P2PB5: J8.16, U17.15 (PB5)
/P2PB6: J8.17, U17.16 (PB6)
/P2PB7: J8.18, U17.17 (PB7)
/PA0: J4.2, U1.34 (PA0)
/PA1: J4.3, U1.33 (PA1)
/PA2: J4.4, U1.32 (PA2)
/PA3: J4.5, U1.31 (PA3)
/PA4: J4.6, U1.30 (PA4)
/PA5: J4.7, U1.29 (PA5)
/PA6: J4.8, U1.28 (PA6)
/PA7: J4.9, U1.27 (PA7)
/PE0: JP4.2 (C), U1.43 (PE0)
/PE1: J4.13, U1.45 (PE1)
/PE2: J4.14, U1.47 (PE2)
/PE3: J4.15, U1.49 (PE3)
/PE4: J4.16, U1.44 (PE4)
/PE5: J4.17, U1.46 (PE5)
/PE6: J4.18, U1.48 (PE6)
/PE7: J4.19, U1.50 (PE7)
/PPA0: J5.3, U2.2 (PA0)
/PPA1: J5.4, U2.3 (PA1)
/PPA2: J5.5, U2.4 (PA2)
/PPA3: J5.6, U2.5 (PA3)
/PPA4: J5.7, U2.6 (PA4)
/PPA5: J5.8, U2.7 (PA5)
/PPA6: J5.9, U2.8 (PA6)
/PPA7: J5.10, U2.9 (PA7)
/PPB0: J5.11, U2.10 (PB0)
/PPB1: J5.12, U2.11 (PB1)
/PPB2: J5.13, U2.12 (PB2)
/PPB3: J5.14, U2.13 (PB3)
/PPB4: J5.15, U2.14 (PB4)
/PPB5: J5.16, U2.15 (PB5)
/PPB6: J5.17, U2.16 (PB6)
/PPB7: J5.18, U2.17 (PB7)
/R2IN: J2.3, U9.8 (R2IN)
/RxD: U1.20 (RXD/PD0), U9.9 (R2OUT)
/R/*W: J11.19, U1.6 (R/W), U2.21 (R/~W), U4.1 (A->B), U8.27 (~WE), U14.2, U15.1, U17.21 (R/~W)
/SCK: U1.24 (SCK/PD4)
/SS: U1.25 (SS/PD5)
/T2OUT: J2.2, U9.7 (T2OUT)
/TxD: U1.21 (TXD/PD1), U9.10 (T2IN)
/VRH: J4.20, U1.52 (VRH)
/VRL: J4.11, U1.51 (VRL)
/VS+: C13.1, U9.2 (VS+)
/VS-: C16.2, U9.6 (VS-)
/XTAL: C11.1, R2.2, U1.8 (XTAL), Y1.1
GND: C1.2, C2.2, C3.2, C4.2, C5.2, C6.2, C7.2, C8.2, C9.2, C10.2, C11.2, C12.2, C16.1, C17.2, C18.2, C19.2, C20.2, C21.2, C22.2, C23.2, D1.1 (K), J1.5 (GND), J1.SH (Shield), J2.0 (PAD), J2.5, J4.10, J11.20, JP4.1 (A), SW1.2, U1.1 (VSS), U2.1 (VSS), U3.1 (OE), U3.10 (GND), U4.10 (GND), U5.4 (E1), U5.5 (E2), U5.8 (GND), U6.14 (GND), U6.20 (~CE), U7.14 (GND), U7.20 (~CE), U8.14 (GND), U8.22 (~OE), U9.11 (T1IN), U9.15 (GND), U10.3 (VSS), U11.8 (GND), U12.7 (GND), U13.7 (GND), U14.7 (GND), U15.7 (GND), U16.14 (GND), U16.20 (~CE), U17.1 (VSS)
unnamed: D1.2 (A), R1.1
unnamed: U5.10 (O5), U11.4 (E1), U11.5 (E2)
unnamed: U11.12 (O3), U14.1
unnamed: U11.13 (O2), U13.13
unnamed: U5.15 (O0), U12.1
unnamed: U5.14 (O1), U12.2
unnamed: U5.13 (O2), U12.4
unnamed: U5.12 (O3), U12.5
unnamed: U5.7 (O7), U13.2
unnamed: U5.9 (O6), U13.5
unnamed: U5.11 (O4), U13.10
VCC: C1.1, C2.1, C3.1, C4.1, C5.1, C6.1, C7.1, C8.1, C9.1, C10.1, C13.2, C17.1, C18.1, C19.1, C20.1, C21.1, C22.1, C23.1, J1.1 (VBUS), J4.1, JP4.3 (B), R1.2, RN1.1 (common), U1.26 (VDD), U2.20 (VCC), U2.22 (CS0), U2.24 (CS1), U3.20 (VCC), U4.20 (VCC), U5.16 (VCC), U6.1 (VPP), U6.27 (~PGM), U6.28 (VCC), U7.1 (VPP), U7.27 (~PGM), U7.28 (VCC), U8.28 (VCC), U9.16 (VCC), U10.2 (VDD), U11.16 (VCC), U12.14 (VCC), U13.14 (VCC), U14.14 (VCC), U15.14 (VCC), U16.1 (VPP), U16.27 (~PGM), U16.28 (VCC), U17.20 (VCC), U17.22 (CS0), U17.24 (CS1)

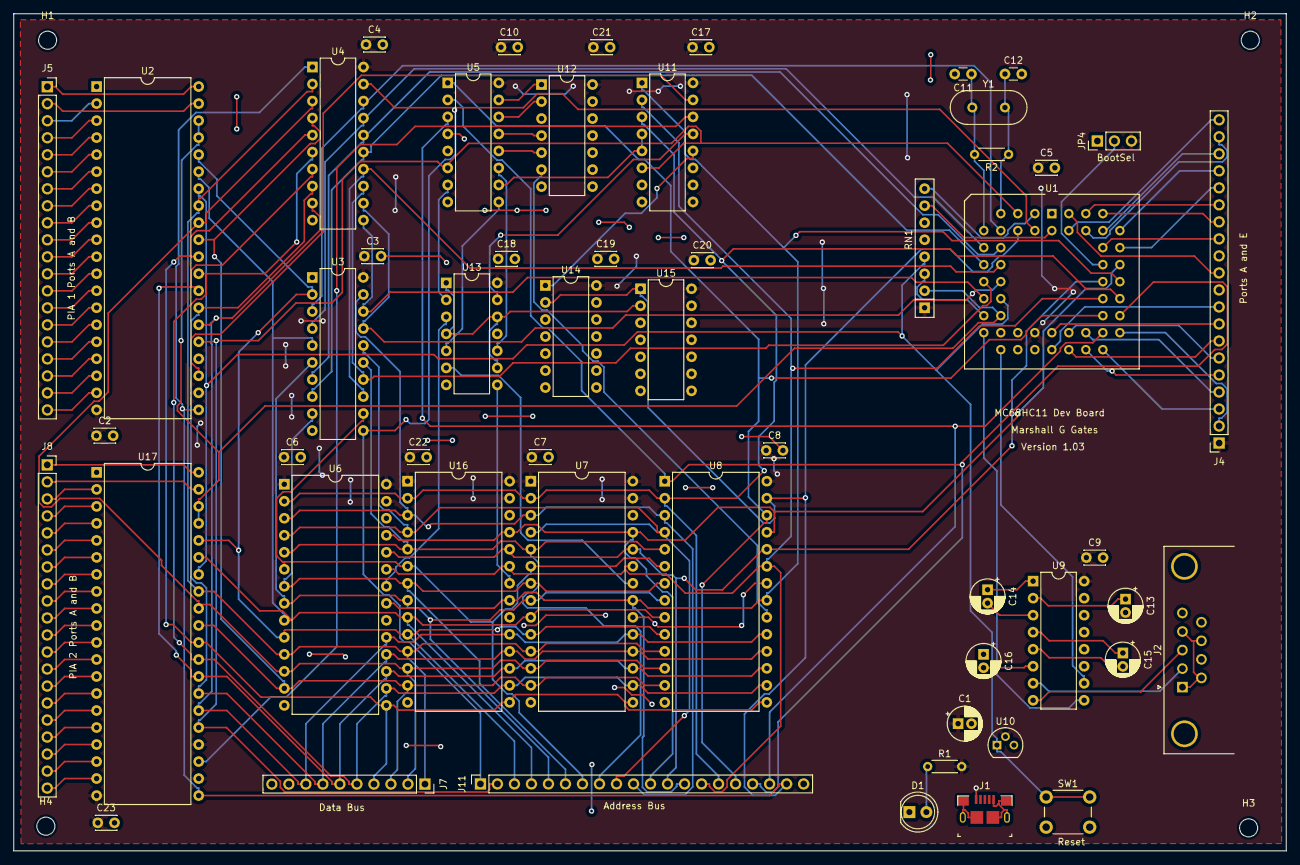
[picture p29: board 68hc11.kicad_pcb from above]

Board: 2 copper layers, 190.0 x 125.0 mm, 58 parts (0 on the bottom side), 131 nets.

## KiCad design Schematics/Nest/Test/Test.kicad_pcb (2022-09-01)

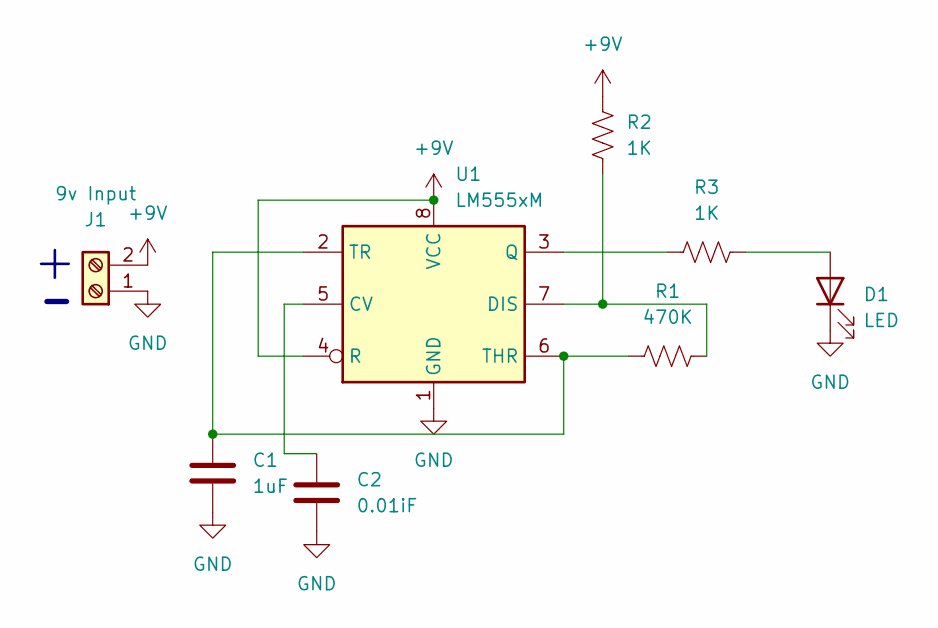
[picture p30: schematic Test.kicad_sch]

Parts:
C1: 1uF; C_Disc_D5.0mm_W2.5mm_P2.50mm
C2: 0.01iF; C_Disc_D5.0mm_W2.5mm_P2.50mm
D1: LED; LED_D5.0mm
J1: 9v Input; TerminalBlock_bornier-2_P5.08mm
R1: 470K; R_Axial_DIN0207_L6.3mm_D2.5mm_P10.16mm_Horizontal
R2, R3: 1K; R_Axial_DIN0207_L6.3mm_D2.5mm_P10.16mm_Horizontal
U1: LM555xM; DIP-8_W7.62mm

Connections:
+9V: J1.2, R2.1, U1.4 (R), U1.8 (VCC)
GND: C1.2, C2.2, D1.1 (K), J1.1, U1.1 (GND)
unnamed: D1.2 (A), R3.2
unnamed: R3.1, U1.3 (Q)
unnamed: C2.1, U1.5 (CV)
unnamed: C1.1, R1.1, U1.2 (TR), U1.6 (THR)
unnamed: R1.2, R2.2, U1.7 (DIS)

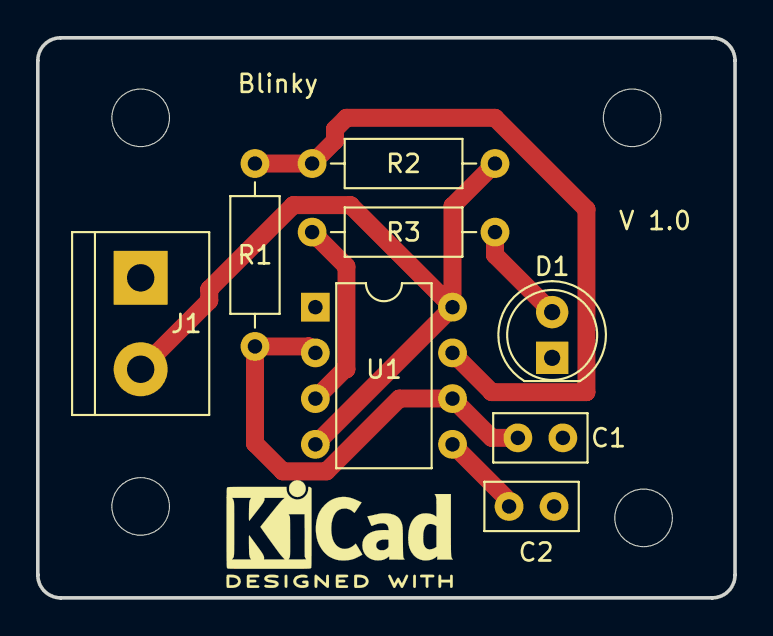
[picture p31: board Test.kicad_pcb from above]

Board: 2 copper layers, 38.7 x 31.1 mm, 8 parts (0 on the bottom side), 7 nets.

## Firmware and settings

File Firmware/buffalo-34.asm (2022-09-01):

*                  BUFFALO
* "Bit User's Fast Friendly Aid to Logical Operation"
*
* Rev 2.0 - 4/23/85 - added disassembler.
*                   - variables now PTRn and TMPn.
* Rev 2.1 - 4/29/85 - added byte erase to chgbyt routine.
* Rev 2.2 - 5/16/85 - added hooks for evb board - acia
*                     drivers, init and host routines.
*           7/8/85  - fixed dump wraparound problem.
*           7/10/85 - added evm board commands.
*                   - added fill instruction.
*           7/18/85 - added jump to EEPROM.
* Rev 2.3 - 8/22/85 - call targco to disconnect sci from host
*                     in reset routine for evb board.
*           10/3/85 - modified load for download through terminal.
* Rev 2.4 - 7/1/86  - Changed DFLOP address to fix conflicts with
*                     EEPROM.  (was at A000)
* Rev 2.5 - 9/8/86  - Modified to provide additional protection from
*                     program run-away on power down.  Also fixed bugs
*                     in MM and MOVE.  Changed to 1 stop bit from 2.
* Rev 2.6 - 9/25/86 - Modified boot routine for variable length download
*                     for use with 'HC11E8.
* Rev 3.0   1/15/87 - EEPROM programming routines consolidated into WRITE.
*                     Fill, Assem, and breakpoints will now do EEPROM.
*                   - Added compare a to $0D to WSKIP routine.
*           2/11/87 - Set up load to detect receiver error.
* Rev 3.2   7/7/87  - Add disassembly to trace.
*                   - Add entries to jump table.
*           9/20/87 - Rewrote trace to use XIRQ, added STOPAT Command
*           11/24/87- Write block protect reg for 'E9 version
*                   - Modified variable length download for use
*                       with 'E9 bootloader (XBOOT command)
* Rev 3.3   3/17/88 - Set I bit to block interrupts on Warm Start and
*                       return from CALL command.
*                   - Added EEMOD Command.
*                   - Rearranged source so that HELP command overlaps
*                       EEPROM in test mode.
*           3/24/88 - Added '+', '-', '=', '.' to MEM and ASM commands.
*                   - Added check for 16 byte boundary to MEM
*                       space sub-command.
*                   - LOAD command now puts dummy (~) command into
*                       inbuff so that any stray cr's won`t hang.
* Rev 3.4   8/15/88 - Changed WRITE subroutine so that config register
*                       gets byte erased before programmed.  The original
*                       value of config is used for EEBYTE so that config
*                       RAM value doesn't get changed in test mode.
*           8/17/88 - Fixed MOVE command so that it doesn't hang when move
*                       is done to a ROM location.
*                   - Added OFFSET command for download offset capability.
*
****************************************************
*    Although the information contained herein,    *
*    as well as any information provided relative  *
*    thereto, has been carefully reviewed and is   *
*    believed accurate, Motorola assumes no        *
*    liability arising out of its application or   *
*    use, neither does it convey any license under *
*    its patent rights nor the rights of others.   *
****************************************************

***************
*   EQUATES   *
***************
*Author EQU  Tony Fourcroy
RAMBS   EQU  $0000      start of ram
REGBS   EQU  $1000      start of registers
ROMBS   EQU  $E000      start of rom
DSTREE  EQU  $B600      start of eeprom
DENDEE  EQU  $B7FF      end of eeprom
PORTE   EQU  REGBS+$0A  port e
CFORC   EQU  REGBS+$0B  force output compare
TCNT    EQU  REGBS+$0E  timer count
TOC5    EQU  REGBS+$1E  oc5 reg
TCTL1   EQU  REGBS+$20  timer control 1
TMSK1   EQU  REGBS+$22  timer mask 1
TFLG1   EQU  REGBS+$23  timer flag 1
TMSK2   EQU  REGBS+$24  timer mask 2
BAUD    EQU  REGBS+$2B  sci baud reg
SCCR1   EQU  REGBS+$2C  sci control1 reg
SCCR2   EQU  REGBS+$2D  sci control2 reg
SCSR    EQU  REGBS+$2E  sci status reg
SCDAT   EQU  REGBS+$2F  sci data reg
BPROT   EQU  REGBS+$35  block protect reg
OPTION  EQU  REGBS+$39  option reg
COPRST  EQU  REGBS+$3A  cop reset reg
PPROG   EQU  REGBS+$3B  ee prog reg
HPRIO   EQU  REGBS+$3C  hprio reg
CONFIG  EQU  REGBS+$3F  config register
DFLOP   EQU  $4000      evb d flip flop
DUART   EQU  $D000      duart address
PORTA   EQU  DUART
PORTB   EQU  DUART+8
ACIA    EQU  $9800      acia address
PROMPT  EQU  '>'
BUFFLNG EQU  35
CTLA    EQU  $01        exit host or assembler
CTLB    EQU  $02        send break to host
CTLW    EQU  $17        wait
CTLX    EQU  $18        abort
DEL     EQU  $7F        abort
EOT     EQU  $04        end of text/table
SWI     EQU  $3F

***************
*     RAM     *
***************
        ORG  $2D
*** Buffalo ram space ***
        RMB  20    user stack area
USTACK  RMB  30    monitor stack area
STACK   RMB  1
REGS    RMB  9     user's pc,y,x,a,b,c
SP      RMB  2     user's sp
INBUFF  RMB  BUFFLNG    input buffer
ENDBUFF EQU  *
COMBUFF RMB  8     command buffer
SHFTREG RMB  2     input shift register
STREE   RMB  2     eeprom start address
ENDEE   RMB  2     eeprom end address
BRKTABL RMB  8     breakpoint table
AUTOLF  RMB  1     auto lf flag for i/o
IODEV   RMB  1     0=sci,  1=acia, 2=duartA, 3=duartB
EXTDEV  RMB  1     0=none, 1=acia, 2=duart,
HOSTDEV RMB  1     0=sci,  1=acia,           3=duartB
COUNT   RMB  1     # characters read
CHRCNT  RMB  1     # characters output on current line
PTRMEM  RMB  2     current memory location
LDOFFST RMB  2     offset for download

*** Buffalo variables - used by: ***
PTR0    RMB  2     main,readbuff,incbuff,AS
PTR1    RMB  2     main,BR,DU,MO,AS,EX
PTR2    RMB  2     EX,DU,MO,AS
PTR3    RMB  2     EX,HO,MO,AS
PTR4    RMB  2     EX,AS
PTR5    RMB  2     EX,AS,BOOT
PTR6    RMB  2     EX,AS,BOOT
PTR7    RMB  2     EX,AS
PTR8    RMB  2     AS
TMP1    RMB  1     main,hexbin,buffarg,termarg
TMP2    RMB  1     GO,HO,AS,LOAD
TMP3    RMB  1     AS,LOAD
TMP4    RMB  1     TR,HO,ME,AS,LOAD
*** Vector jump table ***
JSCI    RMB   3
JSPI    RMB   3
JPAIE   RMB   3
JPAO    RMB   3
JTOF    RMB   3
JTOC5   RMB   3
JTOC4   RMB   3
JTOC3   RMB   3
JTOC2   RMB   3
JTOC1   RMB   3
JTIC3   RMB   3
JTIC2   RMB   3
JTIC1   RMB   3
JRTI    RMB   3
JIRQ    RMB   3
JXIRQ   RMB   3
JSWI    RMB   3
JILLOP  RMB   3
JCOP    RMB   3
JCLM    RMB   3

*****************
*
* ROM starts here *
*
*****************

        ORG  ROMBS

*****************
**  BUFFALO - This is where Buffalo starts
** out of reset.  All initialization is done
** here including determination of where the
** user terminal is (SCI,ACIA, or DUART).
*****************
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

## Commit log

2022-08-02 Adding the initial KiCad schematics
    Just dropped some components on the board. So much left to do.
    [68hc11.kicad_pcb, 68hc11.kicad_sch]
2022-08-03 Start wiring components
    [68hc11.kicad_pcb, 68hc11.kicad_sch]
2022-08-05 Added some more chips to design
    Need to finish Addres block decoding soon.
    [68hc11.kicad_pcb, 68hc11.kicad_sch]
2022-08-05 Added more components to schematic
    [68hc11.kicad_pcb, 68hc11.kicad_sch]
2022-08-05 Added another power monitor datasheet
2022-08-05 Added MAX232 and DB9 for serial comms
    [68hc11.kicad_pcb, 68hc11.kicad_sch]
2022-08-06 Added Crystal and some trace routing
    [68hc11.kicad_pcb, 68hc11.kicad_sch]
2022-08-06 Added low power reset and cleaned up busses
    [68hc11.kicad_pcb, 68hc11.kicad_sch]
2022-08-06 Addes a sample board all the way to gerbers
    [Test-B_Cu.gbr, Test-B_Mask.gbr, Test-B_Paste.gbr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]
2022-08-06 Traced Data Bus between ROM, RAM and PCIA
    [68hc11.kicad_pcb]
2022-08-07 Traced out some more of the address bus
    [68hc11.kicad_pcb]
2022-08-07 Added Screw Terminals for IO Ports
    [68hc11.kicad_pcb, 68hc11.kicad_sch]
2022-08-07 Added bypass caps to chips
    [68hc11.kicad_pcb, 68hc11.kicad_sch]
2022-08-07 Cleaned up AD traces and all warnings
    [68hc11.kicad_pcb, 68hc11.kicad_sch]
2022-08-08 Added power jack
    [68hc11.kicad_pcb, 68hc11.kicad_sch]
2022-08-08 Connected expansion port A
    [68hc11.kicad_pcb]
2022-08-09 Still working on traces
    [68hc11.kicad_pcb]
2022-08-09 Updated bad component values
    Also generated first Bill Of Materials
    [68hc11.csv, 68hc11.kicad_pcb, 68hc11.kicad_sch]
2022-08-10 Reset trace routing
    Start work on memory address decode logic
    [68hc11.kicad_pcb]
2022-08-12 Continueing to rework traces
    Addec VCC Plane
    [68hc11.kicad_pcb, 68hc11.kicad_sch]
2022-08-13 Playing with free routing tool
    ripped it all out when finished
    Still need to add address decode hardware then try again.
    [68hc11.dsn, 68hc11.kicad_pcb]
2022-08-14 Added address logic chips
    Next is layout
    [68hc11.kicad_pcb, 68hc11.kicad_sch]
2022-08-14 Replaced screw terminals with pin headers
    [68hc11.kicad_pcb, 68hc11.kicad_sch]
2022-08-14 Anouther autorouting attempt
    [68hc11.dsn, 68hc11.kicad_pcb]
2022-08-14 Updated chip footprints and generated new vBOM
    [68hc11.csv, 68hc11.kicad_pcb, 68hc11.kicad_sch]
2022-08-14 Updated power to micro usb b receptical
    [68hc11.kicad_pcb, 68hc11.kicad_sch]
2022-08-15 yET ANOTHER LAYOUT AND ROUTING
    [68hc11.csv, 68hc11.dsn, 68hc11.kicad_pcb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]
2022-08-19 Restarting the board layout
    [68hc11.dsn, 68hc11.kicad_pcb]
2022-08-19 Another attempted layout
    [68hc11.dsn, 68hc11.kicad_pcb, 68hc11.kicad_sch]
2022-08-20 Still working on it
    [68hc11.kicad_pcb, 68hc11.kicad_sch]
2022-08-20 Added the Extra ROM Scocket
    [68hc11.kicad_pcb, 68hc11.kicad_sch]
2022-08-21 Added second PIO chip socket
    [68hc11.kicad_pcb, 68hc11.kicad_sch]
2022-08-21 Wired Data Bus
    Corrected discrepency between pin sockets and footprints turned 2 10 pin into 1 20 socket
    [68hc11.kicad_pcb, 68hc11.kicad_sch]
2022-08-22 Wired ROM Chip Selects
    [68hc11.kicad_pcb]
2022-08-22 Reverted symbols to library standard
    [68hc11.kicad_pcb, 68hc11.kicad_sch]
2022-08-23 Trying 4 layer board design
    [68hc11.dsn, 68hc11.kicad_pcb]
2022-08-25 Making progress in the routing
    [68hc11.kicad_pcb]
2022-08-26 More progress
    [68hc11.kicad_pcb]
2022-08-26 Getting closer
    [68hc11.kicad_pcb, 68hc11.kicad_sch]
2022-08-27 A few more traces
    and one bodge trace and via
    [68hc11.kicad_pcb]
2022-08-28 Backup and punt again
    [68hc11.kicad_pcb]
2022-08-29 Board fully traced
    Ran Freetrace and then added nodge patches to fixx islands
    [68hc11.dsn, 68hc11.kicad_pcb]
2022-08-29 Updated ..gitignore for kicad
2022-08-29 Added missing silkscreen text
    [68hc11.kicad_pcb]
2022-08-29 Added PDF of schematic
    [68hc11.kicad_sch]
2022-08-29 Added HTML BOM
    [68hc11.csv, 68hc11.kicad_pcb]
2022-08-29 Clean up paper size and page titles
    [68hc11.kicad_pcb, 68hc11.kicad_sch]
2022-08-30 Making a smaller board layout
    [68hc11.kicad_pcb]
2022-08-31 Rerouting board
    Generated new Dynamic BOM
    [68hc11.dsn, 68hc11.kicad_pcb]
2022-08-31 Finished routing smaller board
    [68hc11.kicad_pcb]
2022-09-01 Added mounting holes
    Added board name and version to silkscreen
    Generated new PDF, BOM and Gerbers
    [68hc11.kicad_pcb, 68hc11.kicad_sch]
2022-09-01 Updated gitignore to allow latest gerber files
    Just not any of the versioned zip files
    [68hc11-B_Cu.gbr, 68hc11-B_Mask.gbr, 68hc11-B_Paste.gbr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]
2022-09-03 Cleanup schematic layout
    [68hc11.kicad_sch]
2022-09-13 Added board image
2022-09-25 Moved RAM ~CS lable
    [68hc11.kicad_sch]
2022-09-29 Added third party 3d models
    For processor socket as the Package_LLC 3d shape folder is missing
    For micro usb b socket, but it doesn't show up
    [68hc11.kicad_pcb]
2022-11-10 Fixed mounting hole size
    [68hc11.kicad_pcb]
2022-11-10 Correctly fixed mounting hole size
    Did it with the footprint like you are supposed to do.
    [68hc11.kicad_pcb]
